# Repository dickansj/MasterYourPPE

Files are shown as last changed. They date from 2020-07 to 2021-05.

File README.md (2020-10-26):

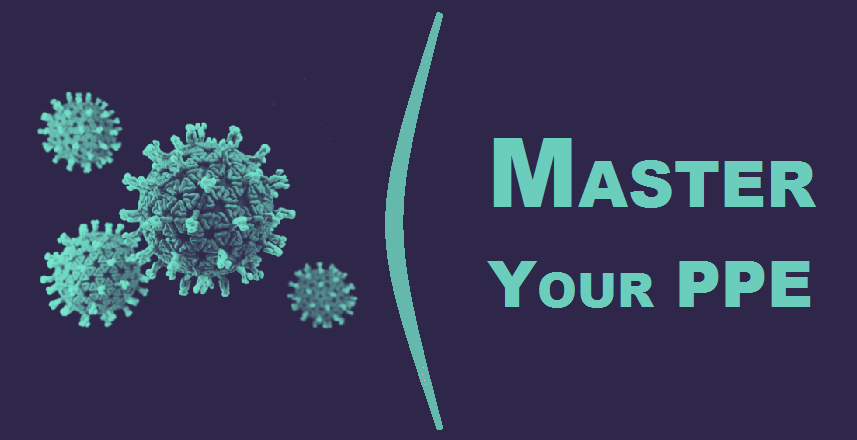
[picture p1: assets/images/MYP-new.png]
Master Your PPE favicon


# Master Your PPE
 

> This repository contains resources for [MasterYourPPE](https://MasterYourPPE.com/), a design project aimed at developing and sharing simple, scalable solutions for better personal protective equipment (PPE). It is built using the [Academic theme](https://sourcethemes.com/academic/) for [Hugo](https://gohugo.io/) and deployed on [Netlify](https://www.netlify.com/).

## Our Vision
*To develop and distribute **easily scalable PPE designs** and simple safe-usage guidelines for the public in order to **protect and educate** the community.*

- We are driven by a focus on maintaining empathy, simplicity, sustainability, and accessibility in our solutions.
- Our goal is to take our PPE designs through the development and iteration process before broadly distributing the ideas.
- Our solutions should be accessible to everyone in our communities, including marginalized and under-resourced groups, and essential workers.
- We plan to collaborate with medical professionals to design the most effective homemade PPE we can, and to spread high-quality information to our community.
- We hope that our work can serve as a framework for others to use and build upon during global health crises now and in the future.

## Getting Started
- Visit https://MasterYourPPE.com/ or our [wiki](https://github.com/dickansj/MasterYourPPE/wiki) to see our array of PPE solutions and resources for healthcare workers and the general public.

- [Contact us](https://masteryourppe.com/#contact) if you are interested in getting involved or finding out more. Have you adapted your PPE to perform better or add comfort? Let us know! We are especially interested to continue hearing from healthcare professionals to engage your experience and better understand your PPE needs.

## License and Disclaimer
The content of this project, including all documentation and hardware designs, is released under the [MIT license](https://github.com/dickansj/MasterYourPPE/blob/master/LICENSE.md) (:copyright: 2020-present Master Your PPE contributors). The Hugo Academic theme (:copyright: 2016-present George Cushen) used to format and display some of this content is also released under the [MIT license](https://github.com/dickansj/MasterYourPPE/blob/master/LICENSE.md).

Our project content has not been reviewed to the standards of the scientific community, and so it should not be construed as medical advice. We believe our testing supports the hypothesis that these designs can make your PPE more effective at protection, but we offer no conclusions regarding health effects or safety. All content is licensed without warranty.

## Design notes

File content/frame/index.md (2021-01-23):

---
title: "Master Your PPE on YouTube"  # Add a page title.
summary: "Easily make your own mask frame to improve the seal and efficacy of your face mask."  # Add a page description.
type: "widget_page"  # Page type is a Widget Page
---

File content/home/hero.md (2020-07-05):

+++
# Hero widget.
widget = "hero"  # See https://sourcethemes.com/academic/docs/page-builder/
headless = true  # This file represents a page section.
active = true  # Activate this widget? true/false
weight = 10  # Order that this section will appear.

title = "Master Your PPE"

# Hero image (optional). Enter filename of an image in the `static/img/` folder.
hero_media = "hero-academic.png"

[design.background]
  # Apply a background color, gradient, or image.
  #   Uncomment (by removing `#`) an option to apply it.
  #   Choose a light or dark text color by setting `text_color_light`.
  #   Any HTML color name or Hex value is valid.

  # Background color.
  # color = "navy"
  
  # Background gradient.
  gradient_start = "#4bb4e3"
  gradient_end = "#2b94c3"
  
  # Background image.
  # image = ""  # Name of image in `static/img/`.
  # image_darken = 0.6  # Darken the image? Range 0-1 where 0 is transparent and 1 is opaque.
  # image_size = "cover"  #  Options are `cover` (default), `contain`, or `actual` size.
  # image_position = "center"  # Options include `left`, `center` (default), or `right`.
  # image_parallax = true  # Use a fun parallax-like fixed background effect? true/false
  
  # Text color (true=light or false=dark).
  text_color_light = true

# Call to action links (optional).
#   Display link(s) by specifying a URL and label below. Icon is optional for `[cta]`.
#   Remove a link/note by deleting a cta/note block.
[cta]
  url = "https://github.com/dickansj/MasterYourPPE/wiki/Improve-Your-Mask-With-a-Frame"
  label = "Step-by-step Guide"
  icon_pack = "fas"
  icon = "list-ol"

[cta_alt]
  url = "https://github.com/dickansj/MasterYourPPE/wiki/Improve-Your-Mask-With-a-Frame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"
  label = "Share results with #MasterYourPPE"

# Note. An optional note to show underneath the links.
## [cta_note]
##   label = '<a class="js-github-release" href="https://sourcethemes.com/academic/updates" data-repo="gcushen/hugo-academic">Latest release<!-- V --></a>'
+++
**to keep yourself and those around you healthy.**

Learn how in this **1-minute video**

<iframe width="100%" height="315" src="https://www.youtube.com/embed/KZgRVWYM7rY" frameborder="0" allow="accelerometer; autoplay; encrypted-media; gyroscope; picture-in-picture" allowfullscreen></iframe>

<!--
<span style="text-shadow: none;"><a class="github-button" href="https://github.com/dickansj/ppe-solutions" data-icon="octicon-star" data-size="large" data-show-count="false" aria-label="Star this on GitHub">Star</a><script async defer src="https://buttons.github.io/buttons.js"></script></span>
-->

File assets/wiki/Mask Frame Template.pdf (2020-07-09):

### Mask Frame Template

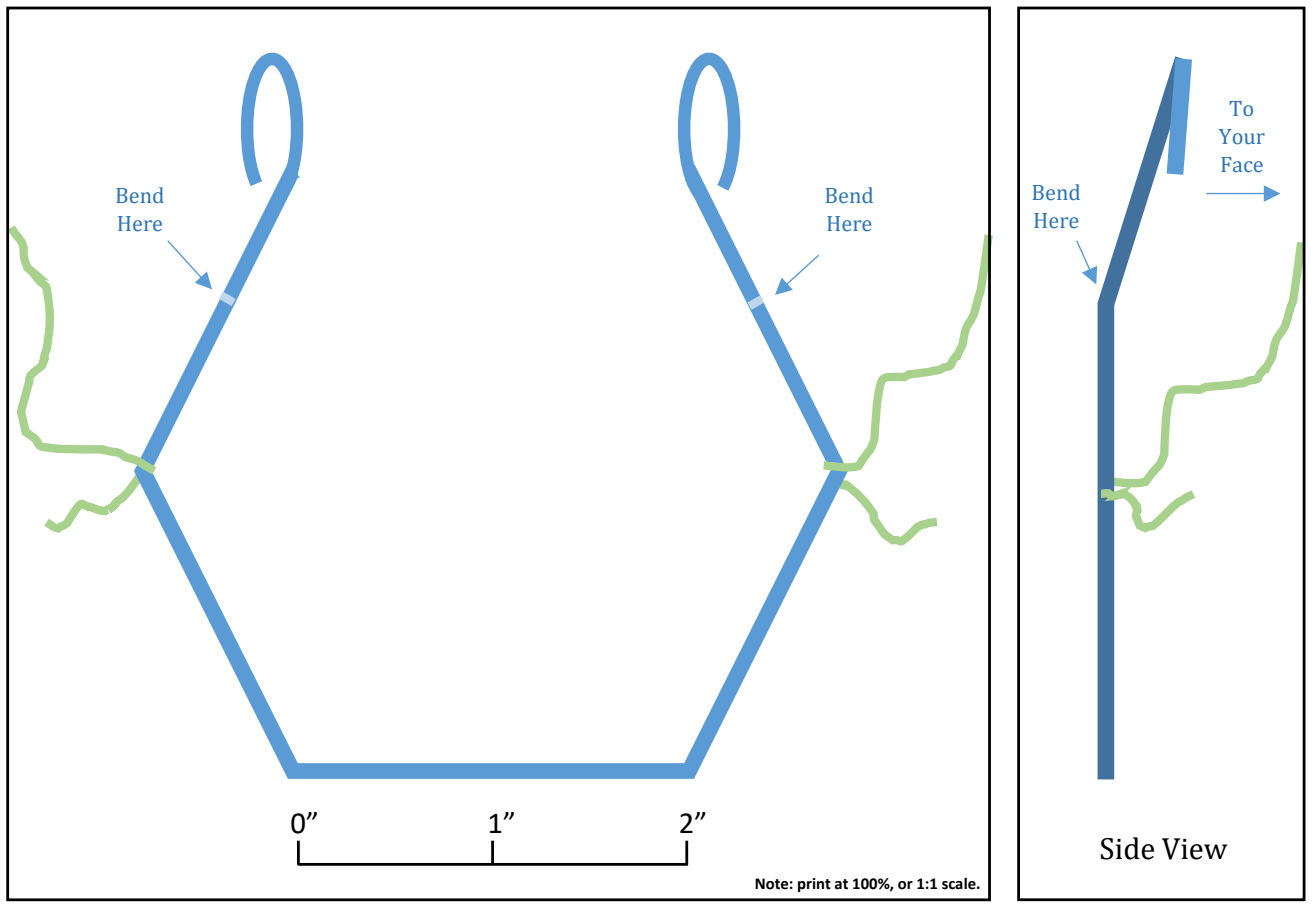
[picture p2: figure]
Side View; Bend Here; To Your Face; Note: print at 100%, or 1:1 scale.

Mask Frame Construction

1. Cut a 12 inch length of 12-gauge solid-core copper wire. Use wire cutters, or use scissors to score the wire then bend it back and forth until it breaks.
2. Loop the wire back about a half inch at both ends for safety. Use long-nose pliers or bend using the spaces in a fork.
3. On a flat surface, like a table, bend the wire into a hexagon shape leaving the top of the shape open. Try to make each side of the hexagon about 2 inches long. You can trace the template above to guide your bending.
4. Bend the wire slightly about an inch from the looped ends to one side of the hexagon shape. This will help push the mask material down against your face and on either side of your nose to stop the side leaks.
5. Cut a 20 inch length of elastic band. Or, take a string or shoelace and measure around your head and cut a length about 3 inches longer than the circumference around your head.
6. Turn the elastic or string once around the wire frame then make a tight knot so that it doesn’t side down the wire too easily. Finally, slide the knots along the wire to the middle bends of the hexagon shape like in the template picture.
7. Looking at yourself in the mirror, put a mask on then place the frame over it. Be careful, the elastic band can snap the frame into your face! Next, bend the wire to adjust the fit of your frame so that it presses comfortably all around your face, especially on either side of your nose. You may need to adjust the length of the elastic or string if the frame feels too tight or too loose. A good test is wearing glasses, if they fog up, the frame isn’t doing its job.

Tips: Pull out a bit of mask material in front of your mouth for breathing comfort. The mask and frame should be comfortable to wear for about 2 hours. Find a safe place to remove your mask and give your face a few minutes to breathe and recover.

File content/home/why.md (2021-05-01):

+++

## This is a template for a blank page section.
## Copy into a new md file. Remember to change active to "true" and use weight to set order on page.
## You can use the other options below, just uncomment as needed.
## Place any html after the bottom 3 plus signs. You can use the div container with Bootstrap classes.
## See https://getbootstrap.com/docs/4.5/layout/grid/ and the docs there (or other content/home md files on this site) for examples.

widget = "blank"  # See https://sourcethemes.com/academic/docs/page-builder/
headless = true  # This file represents a page section.
active = true  # Activate this widget? true/false
weight = 10  # Order that this section will appear.

title = ""
subtitle = ""

[design]
  # Choose how many columns the section has. Valid values: 1 or 2.
  columns = "1"

[design.background]
  # Apply a background color, gradient, or image.
  #   Uncomment (by removing `#`) an option to apply it.
  #   Choose a light or dark text color by setting `text_color_light`.
  #   Any HTML color name or Hex value is valid.

  # Background color.
  # color = "navy"
  
  # Background gradient.
  #gradient_start = "#80CED7"
  #gradient_end = "#007EA7"
  
  # Background image.
  # image = "image.jpg"  # Name of image in `static/img/`.
  # image_darken = 0.6  # Darken the image? Range 0-1 where 0 is transparent and 1 is opaque.
  # image_size = "cover"  #  Options are `cover` (default), `contain`, or `actual` size.
  # image_position = "center"  # Options include `left`, `center` (default), or `right`.
  # image_parallax = true  # Use a fun parallax-like fixed background effect? true/false
  
  # Text color (true=light or false=dark).
  text_color_light = false

[design.spacing]
  # Customize the section spacing. Order is top, right, bottom, left.
  padding = ["20px", "0", "20px", "0"]

[advanced]
 # Custom CSS. 
 css_style = ""
 
 # CSS class.
 css_class = ""
+++

<div class="container-fluid">
  <div class="row featurette">
    <div class="col-xs-12 col-sm-12 col-md-12 col-lg-12 col-xl-12 section-heading">
      <h1><b>Master your PPE!</b></h1>
    </div>
  </div> 
  <div class="row align-items-center">
        
    <div class="col-xs-6 col-sm-6 col-md-6 col-lg-6 col-xl-6" style="text-align: center">
      <span class="lead"; style="color: #83cabb">&#35;myppe</span>&nbsp;&nbsp;<a href="https://www.instagram.com/masteryourppe/" target="_blank"><i class="fab fa-instagram fa-lg"></i></a>&nbsp;&nbsp;<a href="https://www.youtube.com/channel/UCWnhMrXAAiUKiis0FMS9hzg" target="_blank"><i class="fab fa-youtube"></i></a>&nbsp;&nbsp;<a href="https://www.linkedin.com/company/master-your-ppe" target="_blank"><i class="fab fa-linkedin-in fa-lg"></i></a>
    </div>
    
  </div>
  <div class="row align-items-center my-4">
    <div class="col-xs-12 col-sm-12 col-md-6 col-lg-4 col-xl-4">
      <h3>I have my mask . . . now what?</h3>
      <p class="text-left">You know <b><a href="https://www.cdc.gov/coronavirus/2019-ncov/index.html" target="_blank">COVID-19</a></b> is <b><a href="https://covid19.who.int/" target="_blank">still here</a></b>, and you're doing your part to protect yourself and others. Since infections frequently occur when people <b><a href="https://www.nytimes.com/2020/08/11/health/coronavirus-aerosols-indoors.html" target="_blank">breathe in</a></b> contaminated droplets, we need to social distance and correctly wear personal protective equipment (PPE) in order to overcome the virus.</p>
    </div>
    <div class="col-xs-12 col-sm-12 col-md-6 col-lg-3 col-xl-3">
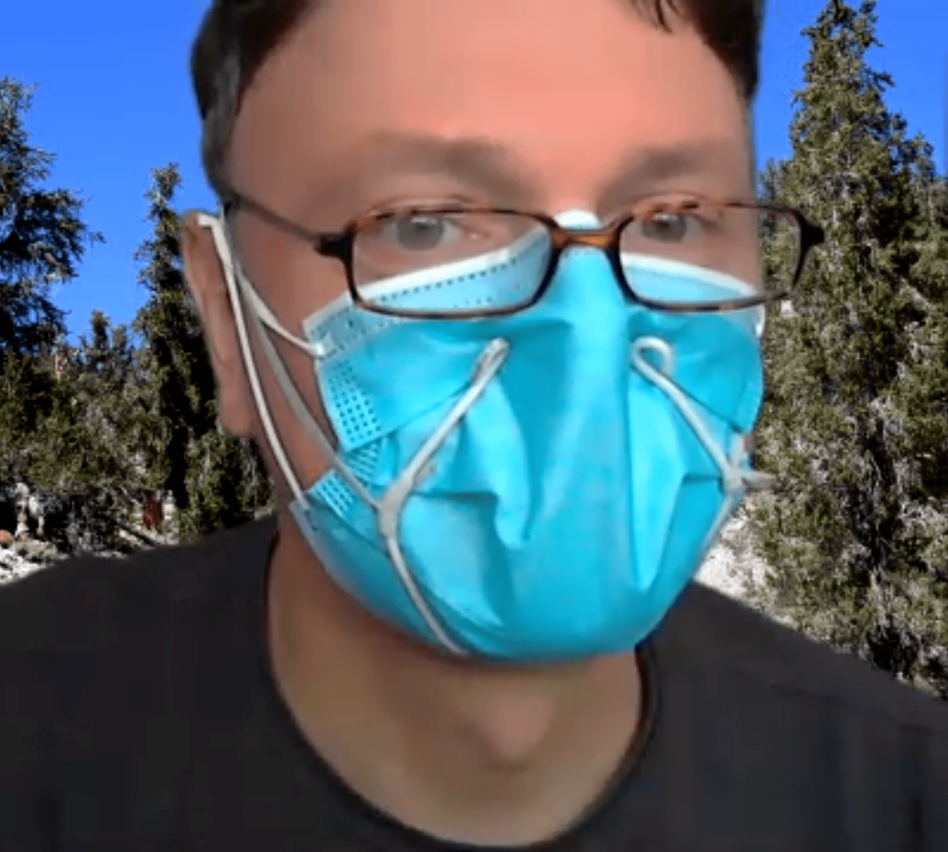
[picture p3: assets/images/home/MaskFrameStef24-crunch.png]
A face mask and mask frame are simple, effective PPE
      
      <p class="text-center"><small><em>Want to make your own mask frame?</em></small><br><b><a href="https://www.youtube.com/watch?v=kpPfyq7r8vA" target="_blank">It's easy, and here's how.</a></b></p>
    </div>
    <div class="col-xs-12 col-sm-12 col-md-12 col-lg-5 col-xl-5">
      <h3>OK, but I'm ready to do more.</h3>
      <p class="text-left">Here you will find <b><a href="https://www.masteryourppe.com/tips/" target="_blank">tips</a></b> and resources to improve the filtration and practicality of your PPE.</p>
      <p class="text-left">Good face coverings can fail because of a weak seal that lets unfiltered air escape or enter through gaps along the sides. By using a simple <b><a href="https://www.youtube.com/watch?v=kpPfyq7r8vA" target="_blank">mask frame</a></b> like the one pictured here, you can effectively reduce the chance of inhaling infected droplets or spreading them to others.</p>
    </div>
  </div> 

</div>

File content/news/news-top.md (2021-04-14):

+++

widget = "blank"  # See https://sourcethemes.com/academic/docs/page-builder/
headless = true  # This file represents a page section.
active = true  # Activate this widget? true/false
weight = 10  # Order that this section will appear.

title = ""
subtitle = ""

[design]
  # Choose how many columns the section has. Valid values: 1 or 2.
  columns = "1"

[design.background]
  # Apply a background color, gradient, or image.
  #   Uncomment (by removing `#`) an option to apply it.
  #   Choose a light or dark text color by setting `text_color_light`.
  #   Any HTML color name or Hex value is valid.

  # Background color.
  # color = "navy"
  
  # Background gradient.
  #gradient_start = "#80CED7"
  #gradient_end = "#007EA7"
  
  # Background image.
  # image = "image.jpg"  # Name of image in `static/img/`.
  # image_darken = 0.6  # Darken the image? Range 0-1 where 0 is transparent and 1 is opaque.
  # image_size = "cover"  #  Options are `cover` (default), `contain`, or `actual` size.
  # image_position = "center"  # Options include `left`, `center` (default), or `right`.
  # image_parallax = true  # Use a fun parallax-like fixed background effect? true/false
  
  # Text color (true=light or false=dark).
  text_color_light = false

[design.spacing]
  # Customize the section spacing. Order is top, right, bottom, left.
  padding = ["20px", "0", "20px", "0"]

[advanced]
 # Custom CSS. 
 css_style = ""
 
 # CSS class.
 css_class = ""
+++

<script src="https://raw.githubusercontent.com/dickansj/MasterYourPPE/master/assets/js/newsCollapse.js"></script>

<div class="container" style="min-width: 0; min-height: 0">

  <div class="row align-items-center px-0" style="justify-content: space-evenly; min-width: 0; min-height: 0; overflow:hidden; flex-wrap:nowrap">
    <div class="col-xs-3 col-sm-3 col-md-3 col-lg-3 col-xl-3 mb-4 px-0" style="min-width: 0; min-height: 0">
      <button class="btn" type="button" style="min-width: 0" data-toggle="collapse" data-target="#science" role="button" aria-expanded="false" aria-controls="science" onclick="location.href = '#articles';">
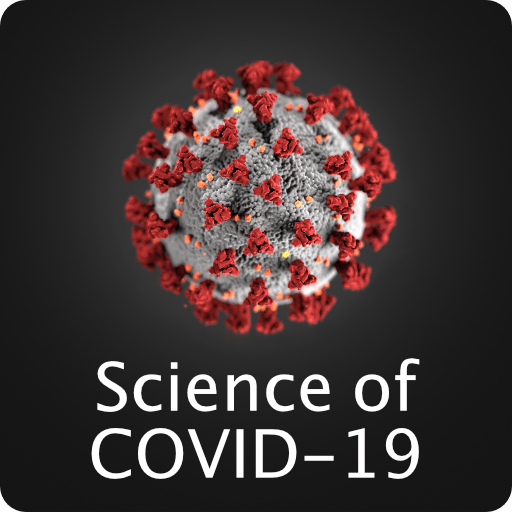
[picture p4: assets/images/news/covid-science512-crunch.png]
Coronavirus Science
        
      </button>
    </div>
    <div class="col-xs-3 col-sm-3 col-md-3 col-lg-3 col-xl-3 mb-4 px-0" style="min-width: 0; min-height: 0">
      <button class="btn" type="button" style="min-width: 0" data-toggle="collapse" data-target="#healthcare" role="button" aria-expanded="false" aria-controls="healthcare" onclick="location.href = '#articles';">
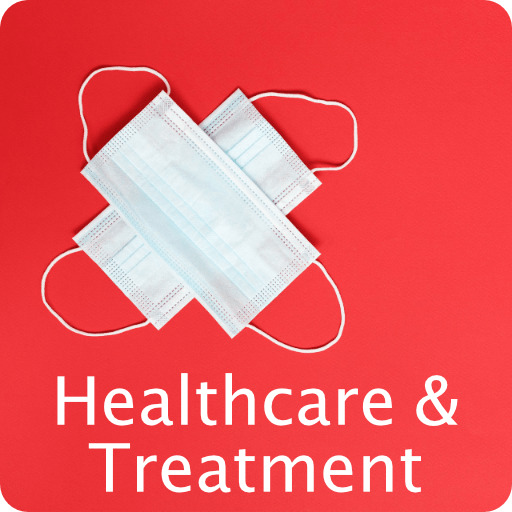
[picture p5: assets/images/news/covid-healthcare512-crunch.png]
Healthcare and Treatment
        
      </button>
    </div>
    <div class="col-xs-3 col-sm-3 col-md-3 col-lg-3 col-xl-3 mb-4 px-0" style="min-width: 0; min-height: 0">
      <button class="btn" type="button" style="min-width: 0" onclick="window.open('https://covid19.who.int/','_blank');">
        <img class="img-fluid" style="box-shadow: 0.4em 0.5em 0.75em -0.3em; border-radius: 1.7em" src="https://github.com/dickansj/MasterYourPPE/blob/master/assets/images/news/who-dashboard512-crunch.png?raw=true alt="WHO Coronavirus Dashboard">
      </button>
    </div>
  </div>

  <p></p>

  <div class="collapse show" id="science">
    <div class="row align-items-center justify-content-around">
      <div class="col-xs-12 col-sm-12 col-md-9 col-lg-9 col-xl-8 my-4">
        <div class="card">
          <div class="card-header lead" style="font-weight: bold; text-align: center">Science of COVID-19</div>
          <a href="https://www.bmj.com/content/372/bmj.n579" target="_blank">
            
          </a>
          <div class="card-body">
            <a href="https://www.bmj.com/content/372/bmj.n579" target="_blank">
              <h5 class="card-title">Risk of Mortality in Patients Infected With SARS-CoV-2 Variant of Concern 202012/1: Matched Cohort Study</h5>
            </a>
            <p class="card-text text-left" style="font-style: italic">A matched cohort study of patients infected with SARS-CoV-2 found a significantly increased mortality risk associated with the viral variant VOC-202012/01.</p>
          </div>
          <div class="card-footer">
            <small class="text-muted">BMJ | Robert Challen, Ellen Brooks-Pollock, Jonathan M. Read, et al.</small>
          </div>
        </div>
      </div>
    </div>
    <div class="row align-items-center justify-content-around">
      <div class="col-xs-12 col-sm-12 col-md-9 col-lg-9 col-xl-8">
        <div class="card">
          <div class="card-header" style="font-weight: bold; text-align: center">More on the Science of COVID-19</div>
          <div class="card-body">
            <p></p>
            <ul><a href="https://jamanetwork.com/journals/jamainternalmedicine/fullarticle/2773576" target="_blank">Estimated SARS-CoV-2 Seroprevalence in the US as of September 2020</a><small class="text-muted"> | JAMA Intern. Med.</small></ul>
            <ul><a href="https://english.elpais.com/society/2020-10-28/a-room-a-bar-and-a-class-how-the-coronavirus-is-spread-through-the-air.html" target="_blank">A Room, a Bar and a Classroom: How the Coronavirus Is Spread Through the Air</a><small class="text-muted"> | El Pais</small></ul>
            <ul><a href="https://amp.cnn.com/cnn/2020/10/30/health/household-spread-covid-19-wellness/index.html" target="_blank">Household Spread of COVID-19 Is Common and Quick, a New CDC Study Finds</a><small class="text-muted"> | CNN</small></ul>
            <ul><a href="https://ashpublications.org/bloodadvances/article/4/20/4990/463793" target="_blank">Reduced Prevalence of SARS-CoV-2 Infection in ABO Blood Group O</a><small class="text-muted"> | Blood Advances</small></ul>
            <ul><a href="https://elemental.medium.com/a-supercomputer-analyzed-covid-19-and-an-interesting-new-theory-has-emerged-31cb8eba9d63" target="_blank">A Supercomputer Analyzed Covid-19 — and an Interesting New Theory Has Emerged</a><small class="text-muted"> | Medium</small></ul>
            <ul><a href="https://depts.washington.edu/pandemicalliance/covid-19-literature-report/latest-reports/" target="_blank">COVID-19 Literature Report (Pre-Prints)</a><small class="text-muted"> | Univ. Washington</small></ul>
            <ul><a href="https://www.nature.com/articles/d41586-020-00502-w" target="_blank">Ongoing Summary of Key COVID-19 Papers</a><small class="text-muted"> | Nature</small></ul>
            <ul><a href="https://www.sciencemag.org/news/2020/09/hidden-immune-weakness-found-14-gravely-ill-covid-19-patients" target="_blank">Hidden Immune Weakness Found in 14% of Gravely Ill COVID-19 Patients</a><small class="text-muted"> | Science</small></ul>
          </div>
        </div>
      </div>     
    </div>
  </div>

  <div class="collapse" id="healthcare">
    <div class="row align-items-center justify-content-around">
      <div class="col-xs-12 col-sm-12 col-md-9 col-lg-9 col-xl-8 my-4">
        <div class="card">
          <div class="card-header lead" style="font-weight: bold; text-align: center">Healthcare & Treatment</div>
          <a href="https://www.nature.com/articles/d41586-021-00722-8" target="_blank">
            
          </a>
          <div class="card-body">
            <a href="https://www.nature.com/articles/d41586-021-00722-8" target="_blank">
              <h5 class="card-title">Rare COVID Reactions Might Hold Key to Variant-Proof Vaccines</h5>
            </a>
            <p class="card-text text-left" style="font-style: italic">Some people mount an immune response able to fend off a menagerie of coronavirus variants.</p>
          </div>
          <div class="card-footer">
            <small class="text-muted">Nature | Ewen Callaway</small>
          </div>
        </div>
      </div>
    </div>
    <div class="row align-items-center justify-content-around">
      <div class="col-xs-12 col-sm-12 col-md-9 col-lg-9 col-xl-8">
        <div class="card">
          <div class="card-header" style="font-weight: bold; text-align: center">More on Healthcare & Treatment</div>
          <div class="card-body">
            <p></p>
            <ul><a href="https://www.newscientist.com/article/2261092-do-oxford-astrazeneca-covid-19-vaccine-results-stand-up-to-scrutiny/" target="_blank">Do Oxford/AstraZeneca COVID-19 Vaccine Results Stand Up to Scrutiny?</a><small class="text-muted"> | New Scientist</small></ul>
            <ul><a href="https://www.ashp.org/-/media/8CA43C674C6D4335B6A19852843C4052.ashx" target="_blank">Assessment of Evidence for COVID-19-Related Treatment: An Updated Summary of Treatments</a><small class="text-muted"> | Amer. Soc. of Health-System Pharmacists</small></ul>            
            <ul><a href="https://www.sciencemag.org/news/2020/09/provocative-results-boost-hopes-antibody-treatment-covid-19" target="_blank">Regeneron’s ‘Provocative Results’ Boost Hopes of Antibody Treatment for COVID-19</a><small class="text-muted"> | Science</small></ul>
            <ul><a href="https://coronavirus.jhu.edu/covid-19-basics/understanding-covid-19" target="_blank">Understanding the COVID-19 Pandemic (Public Online Course)</a><small class="text-muted"> | Johns Hopkins University</small></ul>
            <ul><a href="https://coronavirus.jhu.edu/news" target="_blank">Curated Updates From the Coronavirus Resource Center</a><small class="text-muted"> | Johns Hopkins University</small></ul>
          </div>
        </div>
      </div>     
    </div>
  </div>
  
</div>

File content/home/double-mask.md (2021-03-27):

+++

## This is a template for a blank page section.
## Copy into a new md file. Remember to change active to "true" and use weight to set order on page.
## You can use the other options below, just uncomment as needed.
## Place any html after the bottom 3 plus signs. You can use the div container with Bootstrap classes.
## See https://getbootstrap.com/docs/4.5/layout/grid/ and the docs there (or other content/home md files on this site) for examples.

widget = "blank"  # See https://sourcethemes.com/academic/docs/page-builder/
headless = true  # This file represents a page section.
active = true  # Activate this widget? true/false
weight = 20  # Order that this section will appear.

title = ""
subtitle = ""

[design]
  # Choose how many columns the section has. Valid values: 1 or 2.
  columns = "1"

[design.background]
  # Apply a background color, gradient, or image.
  #   Uncomment (by removing `#`) an option to apply it.
  #   Choose a light or dark text color by setting `text_color_light`.
  #   Any HTML color name or Hex value is valid.

  # Background color.
  # color = "navy"
  
  # Background gradient.
  #gradient_start = "#80CED7"
  #gradient_end = "#007EA7"
  
  # Background image.
  # image = "image.jpg"  # Name of image in `static/img/`.
  # image_darken = 0.6  # Darken the image? Range 0-1 where 0 is transparent and 1 is opaque.
  # image_size = "cover"  #  Options are `cover` (default), `contain`, or `actual` size.
  # image_position = "center"  # Options include `left`, `center` (default), or `right`.
  # image_parallax = true  # Use a fun parallax-like fixed background effect? true/false
  
  # Text color (true=light or false=dark).
  text_color_light = false

[design.spacing]
  # Customize the section spacing. Order is top, right, bottom, left.
  padding = ["20px", "0", "20px", "0"]

[advanced]
 # Custom CSS. 
 css_style = ""
 
 # CSS class.
 css_class = ""
+++

<div class="container-fluid">
  <div class="row align-items-center justify-content-between my-4">
    <div class="col-xs-12 col-sm-12 col-md-6 col-lg-4 col-xl-4">
      <h3>What about "double-masking"?</h3>
      <p class="text-left">CDC recently recommended several <b><a href="https://www.cdc.gov/mmwr/volumes/70/wr/mm7007e1.htm?s_cid=mm7007e1_w" target="_blank">mask modifications</a></b> to increase fit, including the use of a mask fitter (frame) or wearing a second mask over a procedure mask.</p>
    </div>
    <div class="col-xs-12 col-sm-12 col-md-6 col-lg-6 col-xl-6">
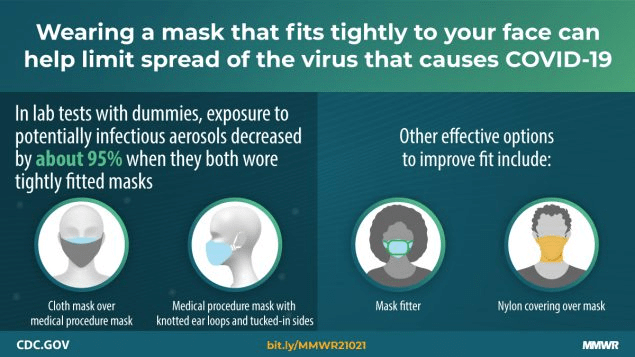
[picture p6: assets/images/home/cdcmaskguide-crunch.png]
CDC mask fit techniques
    	
    </div>
  </div>
  <div class="row align-items-center justify-content-between my-4">
    <div class="col-xs-12 col-sm-12 col-md-6 col-lg-4 col-xl-4">
      <p class="text-left">Watch how we tested our simple mask frame against double-masking to see which approach better prevents unfiltered air leaks. Our results suggest the frame more effectively filters air--all without making it tough to breathe.</p>
    </div>
    <div class="col-xs-12 col-sm-12 col-md-6 col-lg-6 col-xl-6 video-container">
    	<iframe src="https://www.youtube.com/embed/lS0DN3vC22w" frameborder="0" allow="accelerometer; autoplay; encrypted-media; gyroscope; picture-in-picture" allowfullscreen></iframe>
    </div>
  </div> 

</div>

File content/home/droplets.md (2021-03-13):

+++

## This is a template for a blank page section.
## Copy into a new md file. Remember to change active to "true" and use weight to set order on page.
## You can use the other options below, just uncomment as needed.
## Place any html after the bottom 3 plus signs. You can use the div container with Bootstrap classes.
## See https://getbootstrap.com/docs/4.5/layout/grid/ and the docs there (or other content/home md files on this site) for examples.

widget = "blank"  # See https://sourcethemes.com/academic/docs/page-builder/
headless = true  # This file represents a page section.
active = true  # Activate this widget? true/false
weight = 40  # Order that this section will appear.

title = ""
subtitle = ""

[design]
  # Choose how many columns the section has. Valid values: 1 or 2.
  columns = "1"

[design.background]
  # Apply a background color, gradient, or image.
  #   Uncomment (by removing `#`) an option to apply it.
  #   Choose a light or dark text color by setting `text_color_light`.
  #   Any HTML color name or Hex value is valid.

  # Background color.
  # color = "navy"
  
  # Background gradient.
  #gradient_start = "#80CED7"
  #gradient_end = "#007EA7"
  
  # Background image.
  # image = "image.jpg"  # Name of image in `static/img/`.
  # image_darken = 0.6  # Darken the image? Range 0-1 where 0 is transparent and 1 is opaque.
  # image_size = "cover"  #  Options are `cover` (default), `contain`, or `actual` size.
  # image_position = "center"  # Options include `left`, `center` (default), or `right`.
  # image_parallax = true  # Use a fun parallax-like fixed background effect? true/false
  
  # Text color (true=light or false=dark).
  text_color_light = false

[design.spacing]
  # Customize the section spacing. Order is top, right, bottom, left.
  padding = ["20px", "0", "20px", "0"]

[advanced]
 # Custom CSS. 
 css_style = ""
 
 # CSS class.
 css_class = ""
+++

<div class="container-fluid">
  
  <div class="row align-items-xl-center">
    <div class="col-xs-12 col-sm-12 col-md-6 col-lg-6 col-xl-8">
      <h3>What is really going on?</h3>
      <p class="text-left">The <b><a href="https://www.nytimes.com/2020/08/11/health/coronavirus-aerosols-indoors.html" target="_blank">latest research</a></b> confirms that most people become infected with Covid-19 by inhaling contaminated droplets that are ejected when talking, singing, eating, sneezing, coughing, etc.</p>
      <p class="text-left">Infectious virus particles have been observed in both large and small droplets. Larger droplets vary in size down to 0.5mm. These fall to the ground quickly, usually within 6 feet of where they are generated.</p>
    </div>
    <div class="col-xs-12 col-sm-12 col-md-6 col-lg-6 col-xl-4 my-4 order-xs-last order-sm-last order-md-first order-lg-first order-xl-first">
      The spread of droplets
    </div>
  </div>

  <div class="row">
    <div class="col-xs-12 col-sm-12 col-md-12 col-lg-12 col-xl-12">
      <p class="text-left">Smaller droplets range in size from about 0.5mm down to 0.001mm and can <b><a href="https://economictimes.indiatimes.com/news/science/coronavirus-can-travel-up-to-8-metres-from-exhalation-linger-in-air-for-hours-mit-scientist-says/articleshow/749283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" target="_blank">remain suspended in air for hours.</a></b> These can also travel long distances on air currents.  In enclosed environments with still air, small droplets can accumulate in the area where they are being generated until the area becomes <b><a href="https://english.elpais.com/society/2020-10-28/a-room-a-bar-and-a-class-how-the-coronavirus-is-spread-through-the-air.html" target="_blank">highly infectious</a></b>.</p>
      <p class="text-left">For these reasons, it is important to wear an <b><a href="https://www.masteryourppe.com/testing/" target="_blank">effective face covering</a></b> and avoid crowds. And, to help lower the risk of Covid-19 transmission further, see these mask-wearing <b><a href="https://www.masteryourppe.com/tips">tips and tricks</a></b>.</p>
    </div>
  </div>

</div>

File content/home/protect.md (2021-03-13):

+++

## This is a template for a blank page section.
## Copy into a new md file. Remember to change active to "true" and use weight to set order on page.
## You can use the other options below, just uncomment as needed.
## Place any html after the bottom 3 plus signs. You can use the div container with Bootstrap classes.
## See https://getbootstrap.com/docs/4.5/layout/grid/ and the docs there (or other content/home md files on this site) for examples.

widget = "blank"  # See https://sourcethemes.com/academic/docs/page-builder/
headless = true  # This file represents a page section.
active = false  # Activate this widget? true/false
weight = 20  # Order that this section will appear.

title = ""
subtitle = ""

[design]
  # Choose how many columns the section has. Valid values: 1 or 2.
  columns = "1"

[design.background]
  # Apply a background color, gradient, or image.
  #   Uncomment (by removing `#`) an option to apply it.
  #   Choose a light or dark text color by setting `text_color_light`.
  #   Any HTML color name or Hex value is valid.

  # Background color.
  # color = "navy"
  
  # Background gradient.
  #gradient_start = "#80CED7"
  #gradient_end = "#007EA7"
  
  # Background image.
  # image = "image.jpg"  # Name of image in `static/img/`.
  # image_darken = 0.6  # Darken the image? Range 0-1 where 0 is transparent and 1 is opaque.
  # image_size = "cover"  #  Options are `cover` (default), `contain`, or `actual` size.
  # image_position = "center"  # Options include `left`, `center` (default), or `right`.
  # image_parallax = true  # Use a fun parallax-like fixed background effect? true/false
  
  # Text color (true=light or false=dark).
  text_color_light = false

[design.spacing]
  # Customize the section spacing. Order is top, right, bottom, left.
  padding = ["20px", "0", "20px", "0"]

[advanced]
 # Custom CSS. 
 css_style = ""
 
 # CSS class.
 css_class = ""
+++

<div class="container-fluid">
  <div class="row align-items-center mt-4">
    <div class="col-xs-12 col-sm-12 col-md-4 col-lg-4 col-xl-4">
      <h3>Will a mask protect me?</h3>
      <p class="text-left">A good face covering that is worn correctly will substantially reduce the chance of breathing infected airborne droplets or of spreading infectious particles to others.</p>
    </div>
    <div class="col-xs-12 col-sm-12 col-md-8 col-lg-8 col-xl-8">
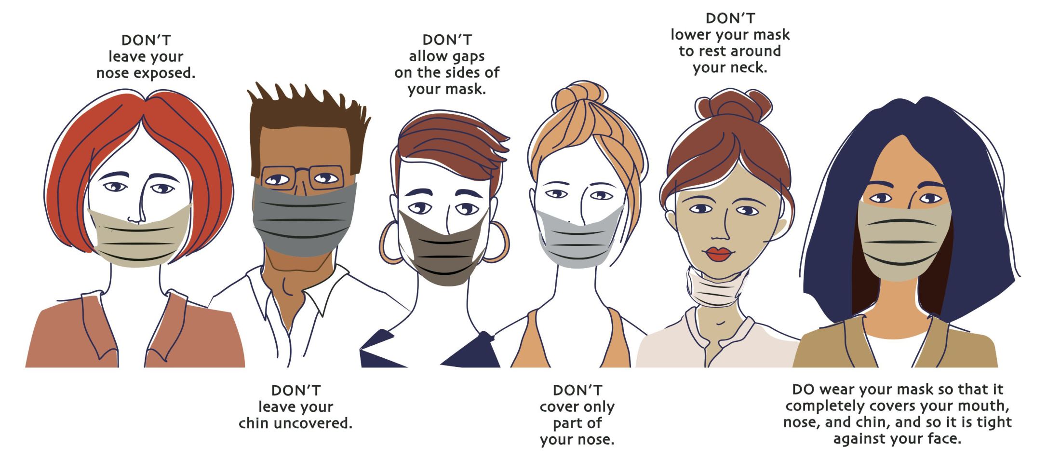
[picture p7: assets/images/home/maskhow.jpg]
How to properly wear a mask
      
      <p class="text-muted small">Graphic by Hollister Breslin</p>
    </div>
  </div> 
  <div class="row">
    <div class="col-xs-12 col-sm-12 col-md-12 col-lg-12 col-xl-12">
      <p class="text-left">Noting the concentration and persistence of small droplets within enclosed areas, it is very important that everyone wear a good face covering. This is to prevent droplets from accumulating in breathing spaces. And of course, it’s prudent to continue to wash hands often, and to avoid crowds.</p>
    </div>
  </div> 
  
</div>

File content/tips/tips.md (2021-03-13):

+++

## This is a template for a blank page section.
## Copy into a new md file. Remember to change active to "true" and use weight to set order on page.
## You can use the other options below, just uncomment as needed.
## Place any html after the bottom 3 plus signs. You can use the div container with Bootstrap classes.
## See https://getbootstrap.com/docs/4.5/layout/grid/ and the docs there (or other content/home md files on this site) for examples.

widget = "blank"  # See https://sourcethemes.com/academic/docs/page-builder/
headless = true  # This file represents a page section.
active = true  # Activate this widget? true/false
weight = 40  # Order that this section will appear.

aliases = [
  "/action/"
]

title = ""
subtitle = ""

[design]
  # Choose how many columns the section has. Valid values: 1 or 2.
  columns = "1"

[design.background]
  # Apply a background color, gradient, or image.
  #   Uncomment (by removing `#`) an option to apply it.
  #   Choose a light or dark text color by setting `text_color_light`.
  #   Any HTML color name or Hex value is valid.

  # Background color.
  # color = "navy"
  
  # Background gradient.
  #gradient_start = "#80CED7"
  #gradient_end = "#007EA7"
  
  # Background image.
  # image = "image.jpg"  # Name of image in `static/img/`.
  # image_darken = 0.6  # Darken the image? Range 0-1 where 0 is transparent and 1 is opaque.
  # image_size = "cover"  #  Options are `cover` (default), `contain`, or `actual` size.
  # image_position = "center"  # Options include `left`, `center` (default), or `right`.
  # image_parallax = true  # Use a fun parallax-like fixed background effect? true/false
  
  # Text color (true=light or false=dark).
  text_color_light = false

[design.spacing]
  # Customize the section spacing. Order is top, right, bottom, left.
  padding = ["20px", "0", "20px", "0"]

[advanced]
 # Custom CSS. 
 css_style = ""
 
 # CSS class.
 css_class = ""
+++

<div class="container-fluid">
  <div class="row">
    <div class="col-xs-12 col-sm-12 col-md-12 col-lg-12 col-xl-12 text-center">
      <h3>What PPE should I wear?</h3>
    </div>
  </div> 
  <div class="row">
    <div class="col-xs-12 col-sm-12 col-md-12 col-lg-12 col-xl-12">
      <p class="text-left">After <b><a href="https://www.masteryourppe.com/testing" target="_blank">testing the filtering efficiency</a></b> of several face masks and common materials used for face coverings, we find that 3-layer disposable masks are very effective at trapping potentially infections airborne droplets. These common mask types are sold at neighborhood drug stores and most hardware stores.  Specifically, look for 3-layer masks (aka surgical masks). And remember to always carry two masks with you: one to wear and one as a spare, in your car, your bag, or your pocket.</p>
    </div>
  </div> 
  <div class="row">
    <div class="col-xs-12 col-sm-12 col-md-12 col-lg-12 col-xl-12 text-center">
      <h3>How do I properly wear a surgical mask?</h3>
    </div>
  </div> 
  <div class="row">
    <div class="col-xs-12 col-sm-12 col-md-12 col-lg-12 col-xl-12">
      <p class="text-left">Wearing a surgical mask correctly may not be obvious.  There are basically <b>two things</b> you must do (in addition to actually wearing the mask on your face, not on your head or under your chin) when in a public setting.  First, pull open the pleats so that the mask covers your chin completely.  Second, bend the nose clip wire down onto your face to customize the fit and seal of the mask.</p>
    </div>
  </div>
  <div class="row my-4">
    <div class="col-xs-12 col-sm-12 col-md-12 col-lg-12 col-xl-12 text-center">
      <h3>What else can I do?</h3>
    </div>
  </div>
  <div class="row align-items-center">
    <div class="col-xs-12 col-sm-12 col-md-8 col-lg-8 col-xl-8">
      <h4>Check your mask type.</h4>
      <p class="text-left">A quick way to check that you have a 3-layer mask, is to cut one open and count the layers.  The two outer ‘hydrophobic’ layers are used to repel moisture, while the inside layer is the melt-blown filter.</p>
      <p class="text-left">By comparison, 2-layer masks lack the innermost filtering layer.  These masks perform poorly at filtering smaller droplets.  Two-layer masks are typically sold at beauty supply stores.</p>
    </div>
    <div class="col-xs-12 col-sm-12 col-md-4 col-lg-4 col-xl-4 order-xs-last order-sm-last order-md-first order-lg-first order-xl-first my-4">
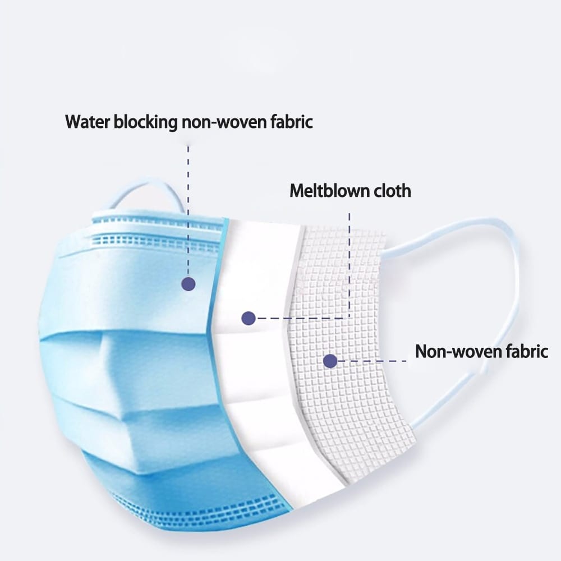
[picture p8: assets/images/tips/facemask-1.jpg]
Check your mask type
      
    </div>
  </div>
  <div class="row align-items-center">
    <div class="col-xs-12 col-sm-12 col-md-8 col-lg-8 col-xl-8">
      <h4>Clips the trick.</h4>
      <p class="text-left">Attach a paper clip to each side of a baseball cap then attach the ear loops of a surgical mask to the clips.  This will save you from having to wear the mask loops around your ears.  Or, if you have access to a 3-D printer, download and print <b><a href="https://github.com/dickansj/MasterYourPPE/blob/master/designs/facemask/maskclip/MaskClipv3.stl" target="_blank">this cap clip STL file</a></b> to do the same thing, in style.</p>
    </div>
    <div class="col-xs-12 col-sm-12 col-md-4 col-lg-4 col-xl-4 order-xs-last order-sm-last order-md-first order-lg-first order-xl-first my-4">
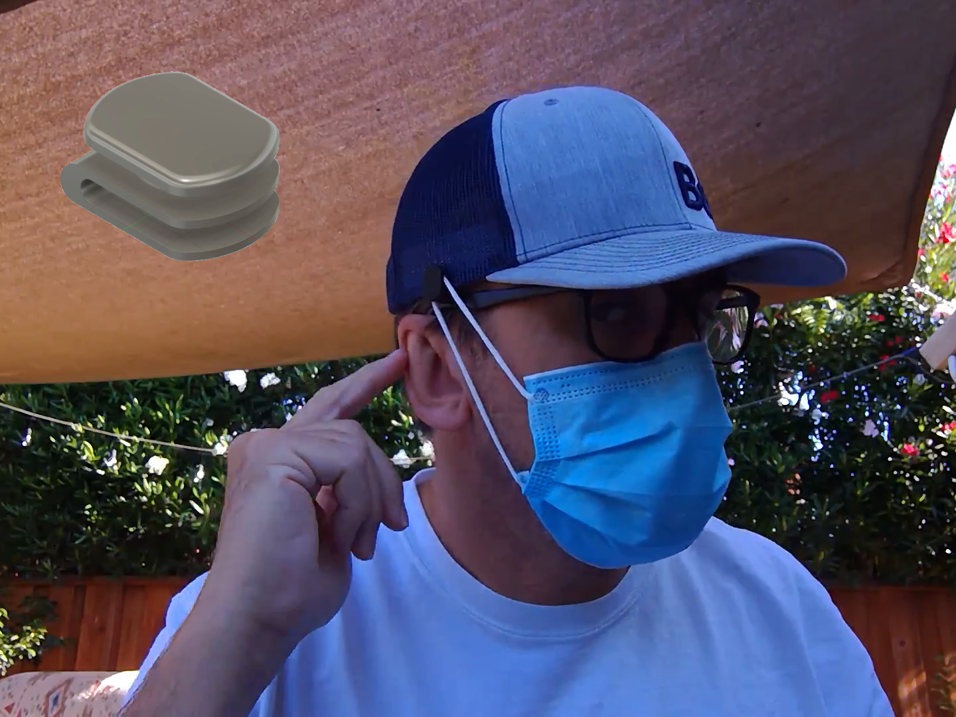
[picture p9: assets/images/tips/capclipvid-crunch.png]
Cap clips will keep your mask loops from straining your ears
      
    </div>
  </div> 
  <div class="row align-items-center">
    <div class="col-xs-12 col-sm-12 col-md-8 col-lg-8 col-xl-8">
      <h4>Some strings attached.</h4>
      <p class="text-left">Tie a string between the ear loops of your mask.  This will keep the loops from rubbing or digging into the skin behind your ears after hours of use.  You can also use the elastic ear loop string itself for this purpose.  Just rip off an ear loop string from an old mask on its way to being trashed.</p>
    </div>
    <div class="col-xs-12 col-sm-12 col-md-4 col-lg-4 col-xl-4 order-xs-last order-sm-last order-md-first order-lg-first order-xl-first my-4">
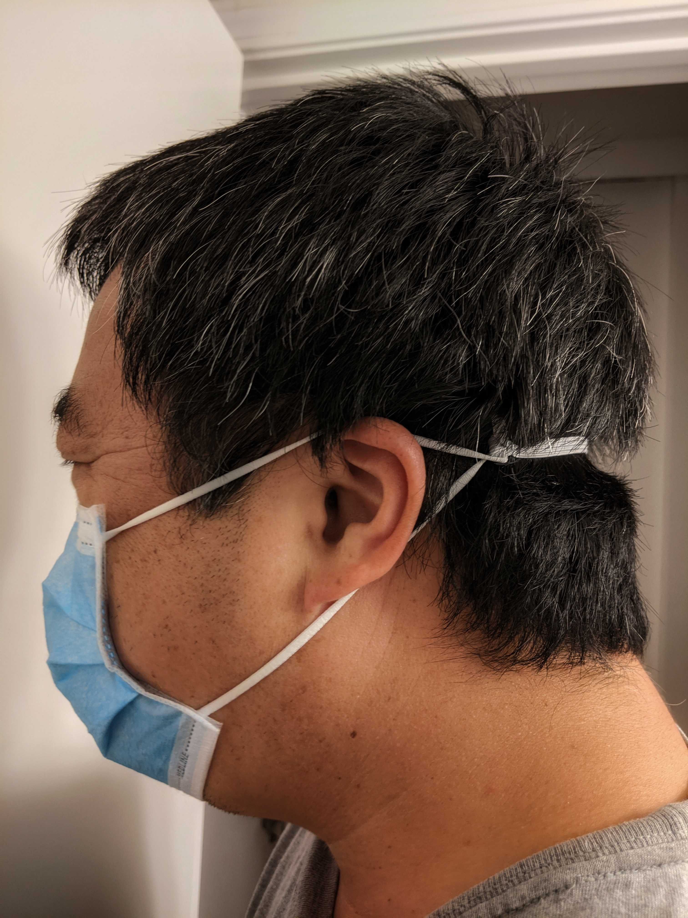
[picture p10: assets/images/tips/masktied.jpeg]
Make your mask time more comfortable
      
    </div>
  </div>  
  <div class="row align-items-center">
    <div class="col-xs-12 col-sm-12 col-md-8 col-lg-8 col-xl-8">
      <h4>Add a mask frame.</h4>
      <p class="text-left">Easily enhance the effectiveness of your face covering by making a mask frame.  Your personalized mask frame will help to seal the air leaks around your face to stop airborne droplets from passing through.  See <b><a href="https://youtu.be/KZgRVWYM7rY" target="_blank">this</a></b> quick how-to video and <b><a href="https://github.com/dickansj/MasterYourPPE/wiki/Improve-Your-Mask-With-a-Frame" target="_blank">print</a></b> a mask frame template with instructions.</p>
      <p class="text-left">You should know that wearing a well-fitting mask for a long time may cause shortness of breath, especially if you are relaxed and breathing shallow.  The solution is to take a few deep breaths while keeping the mask on.  This will help to bring in more fresh air.</p>
    </div>
    <div class="col-xs-12 col-sm-12 col-md-4 col-lg-4 col-xl-4 order-xs-last order-sm-last order-md-first order-lg-first order-xl-first my-4">
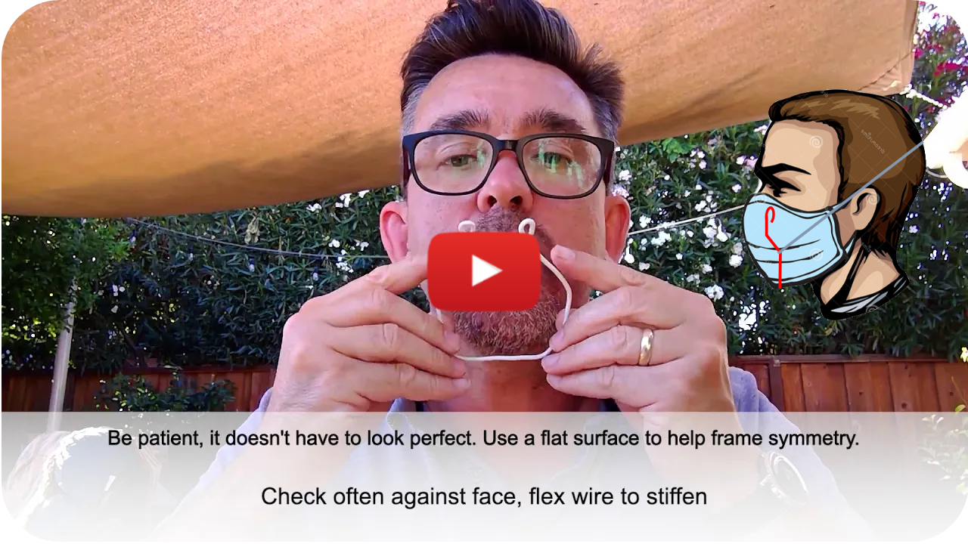
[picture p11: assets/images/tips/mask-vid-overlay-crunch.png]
Add a mask frame
      
    </div>
  </div>
  <div class="row align-items-center">
    <div class="col-xs-12 col-sm-12 col-md-8 col-lg-8 col-xl-8">
      <h4>Completely dried out.</h4>
      <p class="text-left">It’s possible to reuse your surgical mask many times over if it’s had a chance to dry out completely.</p>
      <p class="text-left">Setup an easy mask-rotation program:  First, write numbers on the inside edge on four masks.  Wear the first mask on day 1 then hang it to dry out.  Wear the second mask on day 2 and so on.  When day 5 comes, you can wear the first mask again knowing it has dried out completely.</p>
    </div>
    <div class="col-xs-12 col-sm-12 col-md-4 col-lg-4 col-xl-4 order-xs-last order-sm-last order-md-first order-lg-first order-xl-first my-4">
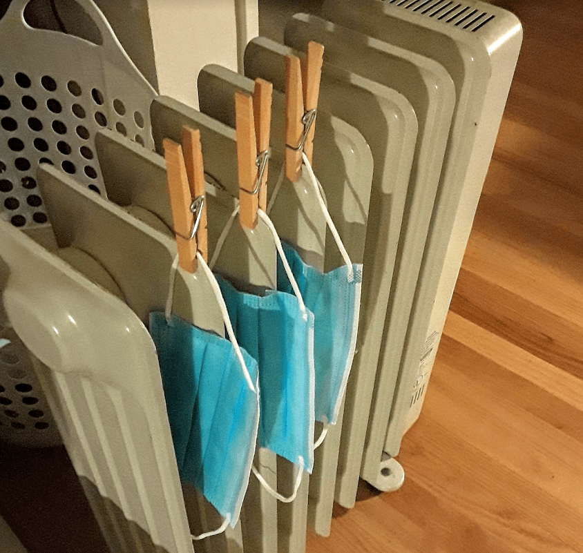
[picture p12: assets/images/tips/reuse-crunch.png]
Reuse your masks safely
      
    </div>
  </div>
  <div class="row align-items-center">
    <div class="col-xs-12 col-sm-12 col-md-8 col-lg-8 col-xl-8">
      <h4>Catch a sneeze.</h4>
      <p class="text-left">Nobody likes to sneeze inside of their mask, gross!  Especially true when you have only one mask with you that needs to stay on for hours.  So, in addition to a spare mask, always carry a clean tissue in your pocket, ready to catch that sneeze.</p>
      <p class="text-left">Remember that one of the main purposes of wearing a mask in public is to stop airborne droplets.  So removing it (even momentarily) to sneeze defeats the objective.  This is where you have to be very diligent in stopping droplets from taking to the air by using a tissue effectively to catch your sneeze.</p>
      <p class="text-left">A tissue is much better at stopping droplets than your bare hands or even the inside of your elbow.  Trash the tissue and wash your hands with soap and water as soon as possible.</p>
    </div>
    <div class="col-xs-12 col-sm-12 col-md-4 col-lg-4 col-xl-4 order-xs-last order-sm-last order-md-first order-lg-first order-xl-first my-4">
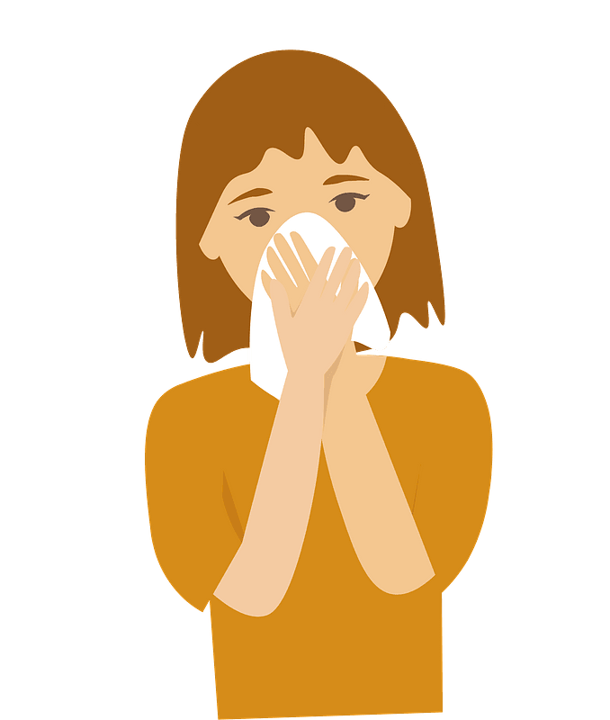
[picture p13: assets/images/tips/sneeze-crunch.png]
Catch your sneeze
      
    </div>
  </div>
  <div class="row align-items-center">
    <div class="col-xs-12 col-sm-12 col-md-8 col-lg-8 col-xl-8">
      <h4>Add a face shield.</h4>
      <p class="text-left">You can make or buy a face shield to wear in conjunction with your face covering for a substantial boost to the effectiveness of just wearing a mask alone.</p>
      <p class="text-left">By wearing a face shield or goggles with your face mask, you can better guard your eyes from larger droplets, which you will more likely encounter when you are within 6 feet of others. CDC <a href="https://www.cdc.gov/coronavirus/2019-ncov/prevent-getting-sick/cloth-face-cover-guidance.html" target="_blank"><b>does not recommend</b></a> using a face shield as a mask <b>substitute</b> because shields typically leave large gaps for droplets around your face. If you have a reusable face shield, you can clean it by following CDC guidelines at the bottom of <a href="https://www.cdc.gov/coronavirus/2019-ncov/hcp/ppe-strategy/eye-protection.html#anchor_1605043382236" target="_blank"><b>this page</b></a>.</p>
    </div>
    <div class="col-xs-12 col-sm-12 col-md-4 col-lg-4 col-xl-4 order-xs-last order-sm-last order-md-first order-lg-first order-xl-first my-4">
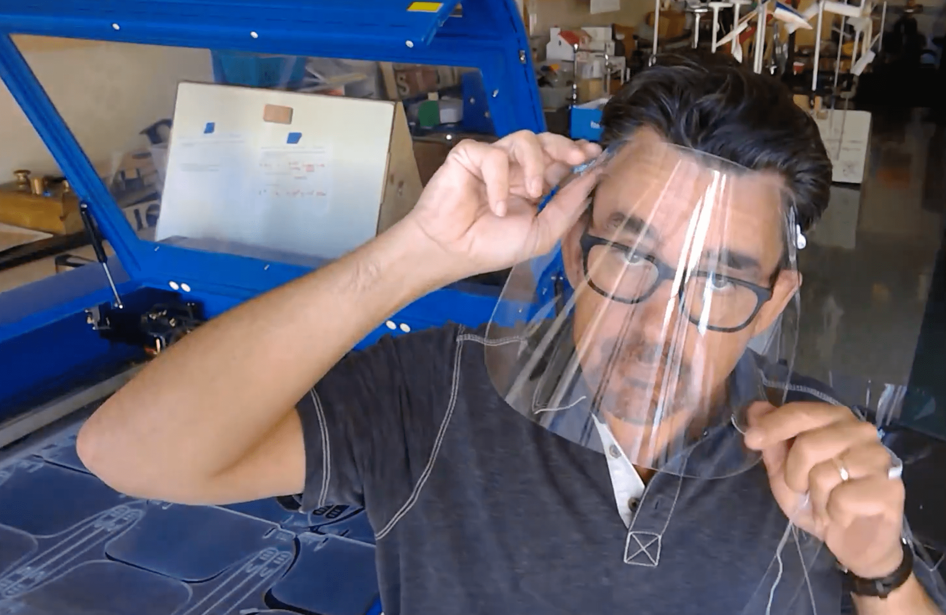
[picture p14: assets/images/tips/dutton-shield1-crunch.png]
Add a face shield
      
    </div>
  </div> 

</div>

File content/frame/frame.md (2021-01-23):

+++

widget = "blank"  # See https://sourcethemes.com/academic/docs/page-builder/
headless = true  # This file represents a page section.
active = true  # Activate this widget? true/false
weight = 10  # Order that this section will appear.

title = ""
subtitle = ""

[design]
  # Choose how many columns the section has. Valid values: 1 or 2.
  columns = "1"

[design.background]
  # Apply a background color, gradient, or image.
  #   Uncomment (by removing `#`) an option to apply it.
  #   Choose a light or dark text color by setting `text_color_light`.
  #   Any HTML color name or Hex value is valid.

  # Background color.
  # color = "navy"
  
  # Background gradient.
  #gradient_start = "#80CED7"
  #gradient_end = "#007EA7"
  
  # Background image.
  # image = "image.jpg"  # Name of image in `static/img/`.
  # image_darken = 0.6  # Darken the image? Range 0-1 where 0 is transparent and 1 is opaque.
  # image_size = "cover"  #  Options are `cover` (default), `contain`, or `actual` size.
  # image_position = "center"  # Options include `left`, `center` (default), or `right`.
  # image_parallax = true  # Use a fun parallax-like fixed background effect? true/false
  
  # Text color (true=light or false=dark).
  text_color_light = false

[design.spacing]
  # Customize the section spacing. Order is top, right, bottom, left.
  padding = ["20px", "0", "20px", "0"]

[advanced]
 # Custom CSS. 
 css_style = ""
 
 # CSS class.
 css_class = ""
+++

<html>
<head>
<meta http-equiv="refresh" content="0;url=https://github.com/dickansj/MasterYourPPE/wiki/Improve-Your-Mask-With-a-Frame" />
<title>Improve Your Mask With a Frame</title>
</head>
</html>

Redirecting to <a href="https://github.com/dickansj/MasterYourPPE/wiki/Improve-Your-Mask-With-a-Frame">the Master Your PPE wiki</a>...

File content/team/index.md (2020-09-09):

---
title: “Who Are We?”  # Add a page title.
summary: "The people and vision behind Master Your PPE"  # Add a page description.
type: "widget_page"  # Page type is a Widget Page
---

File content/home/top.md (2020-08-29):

+++
# A Demo section created with the Blank widget.
# Any elements can be added in the body: https://sourcethemes.com/academic/docs/writing-markdown-latex/
# Add more sections by duplicating this file and customizing to your requirements.

widget = "blank"  # See https://sourcethemes.com/academic/docs/page-builder/
headless = true  # This file represents a page section.
active = false  # Activate this widget? true/false
weight = 10  # Order that this section will appear.

title = ""
subtitle = ""

[design]
  # Choose how many columns the section has. Valid values: 1 or 2.
  columns = "1"

[design.background]
  # Apply a background color, gradient, or image.
  #   Uncomment (by removing `#`) an option to apply it.
  #   Choose a light or dark text color by setting `text_color_light`.
  #   Any HTML color name or Hex value is valid.

  # Background color.
  # color = "navy"
  
  # Background gradient.
  gradient_start = "#80CED7"
  gradient_end = "#007EA7"
  
  # Background image.
  # image = "image.jpg"  # Name of image in `static/img/`.
  # image_darken = 0.6  # Darken the image? Range 0-1 where 0 is transparent and 1 is opaque.
  # image_size = "cover"  #  Options are `cover` (default), `contain`, or `actual` size.
  # image_position = "center"  # Options include `left`, `center` (default), or `right`.
  # image_parallax = true  # Use a fun parallax-like fixed background effect? true/false
  
  # Text color (true=light or false=dark).
  text_color_light = true

[design.spacing]
  # Customize the section spacing. Order is top, right, bottom, left.
  padding = ["20px", "0", "20px", "0"]

[advanced]
 # Custom CSS. 
 css_style = ""
 
 # CSS class.
 css_class = ""
+++

<div class="container-fluid">
  <div class="row">
    <div class="col-xs-12 col-sm-12 col-md-12 col-lg-12 col-xl-12">
      <p class="display-4 text-center mb-0 px-0" style="font-size: calc(145% + 1vw + 1vh);">Master Your PPE</p>
    </div>
    <div class="col-xs-12 col-sm-12 col-md-12 col-lg-12 col-xl-12">
      <p class="lead text-muted text-center mt-0">to keep yourself and those around you healthy.</p>
    </div>
  </div>
</div>
<br>
<div class="container-fluid">
  <div class="row">
    <div class="col-xs-12 col-sm-12 col-md-12 col-lg-6 col-xl-6 mb-4 order-xs-first order-sm-first order-md-first order-lg-last order-xl-last embed-responsive embed-responsive-16by9">
        <iframe class="embed-responsive-item" src="https://www.youtube.com/embed/KZgRVWYM7rY" allow="accelerometer; autoplay; encrypted-media; gyroscope; picture-in-picture" allowfullscreen></iframe>
    </div>
    <div class="col-xs-12 col-sm-12 col-md-12 col-lg-6 col-xl-6 order-xs-last order-sm-last order-md-last order-lg-first order-xl-first my-xs-4 my-sm-4 my-md-4 my-lg-3 my-xl-3">
      <p class = "lead text-center text-lg-left">Learn how in this 1-minute video</p>
      <p class= "cta-btns">
        <a href="https://github.com/dickansj/MasterYourPPE/wiki/Improve-Your-Mask-With-a-Frame" target="_blank" rel="noopener" class="btn cta-btns btn-light btn-lg my-lg-4 my-xl-4 mx-auto d-block float-lg-left" style="color:#32408f; font-size:1.1rem; padding-top: 0.6em; padding-right: 2.1em; padding-bottom: 0.6em; padding-left: 2.1em; line-height: .5; max-width:330px"><i class="fas fa-list-ol pr-1" aria-hidden="true"></i>Step-by-step Guide</a>
      </p>
      <p class= "cta-btns">
        <a class="hero-cta-alt mx-auto d-block float-xs-none float-sm-none float-md-none float-lg-left float-xl-left text-center text-lg-left" href="https://github.com/dickansj/MasterYourPPE/wiki/Improve-Your-Mask-With-a-Frame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" target="_blank" rel="noopener" class="hero-cta-alt pl-4">Share results with #MasterYourPPE <i class="fas fa-angle-right"></i></a>
      </p>
    </div>
  </div>
</div>

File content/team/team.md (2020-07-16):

+++

widget = "blank"  # See https://sourcethemes.com/academic/docs/page-builder/
headless = true  # This file represents a page section.
active = true  # Activate this widget? true/false
weight = 40  # Order that this section will appear.

title = ""
subtitle = ""

[design]
  # Choose how many columns the section has. Valid values: 1 or 2.
  columns = "1"

[design.background]
  # Apply a background color, gradient, or image.
  #   Uncomment (by removing `#`) an option to apply it.
  #   Choose a light or dark text color by setting `text_color_light`.
  #   Any HTML color name or Hex value is valid.

  # Background color.
  # color = "navy"
  
  # Background gradient.
  #gradient_start = "#80CED7"
  #gradient_end = "#007EA7"
  
  # Background image.
  # image = "image.jpg"  # Name of image in `static/img/`.
  # image_darken = 0.6  # Darken the image? Range 0-1 where 0 is transparent and 1 is opaque.
  # image_size = "cover"  #  Options are `cover` (default), `contain`, or `actual` size.
  # image_position = "center"  # Options include `left`, `center` (default), or `right`.
  # image_parallax = true  # Use a fun parallax-like fixed background effect? true/false
  
  # Text color (true=light or false=dark).
  text_color_light = false

[design.spacing]
  # Customize the section spacing. Order is top, right, bottom, left.
  padding = ["20px", "0", "20px", "0"]

[advanced]
 # Custom CSS. 
 css_style = ""
 
 # CSS class.
 css_class = ""
+++

<div class="container my-4">
  <div class="row featurette">
    <div class="col-xs-12 col-sm-12 col-md-12 col-lg-12 col-xl-12 section-heading">
      <h1>Who Are We?</h1>
    </div>
  </div>
  <div class="row align-items-center">
    <div class="col-xs-12 col-sm-4 col-md-4 col-lg-3 col-xl-2 px-4 my-4">
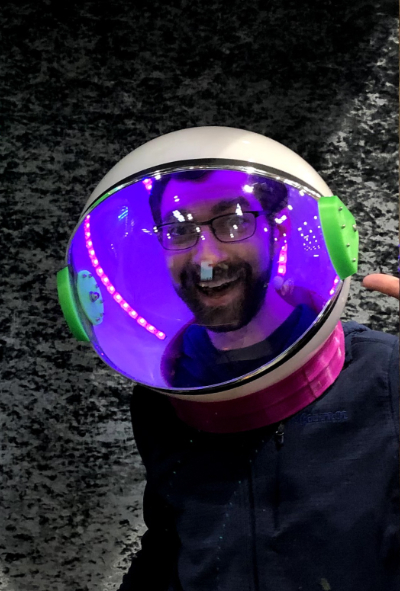
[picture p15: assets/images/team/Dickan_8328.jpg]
Joseph Dickan
      
    </div>
    <div class=" col-xs-12 col-sm-8 col-md-8 col-lg-9 col-xl-10 px-4 my-4">
      <p><b>Joseph Dickan, SJ,</b> is a Jesuit scholastic, educator, and graduate student. He likes neuroscience, computers, and tinkering over a cup of coffee.</p>
    </div>
  </div>
  <div class="row align-items-center">
    <div class="col-xs-12 col-sm-4 col-md-4 col-lg-3 col-xl-2 px-4 my-4">
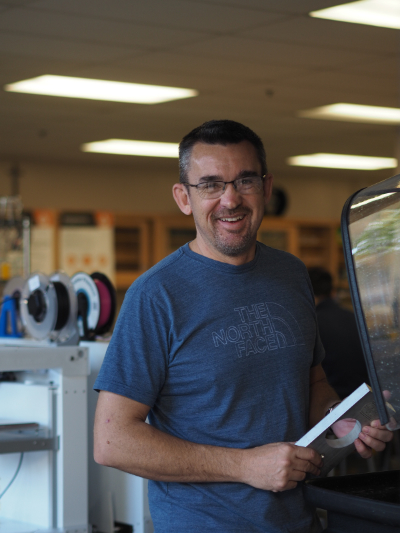
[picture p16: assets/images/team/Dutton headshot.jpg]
David Dutton
      
    </div>
     <div class=" col-xs-12 col-sm-8 col-md-8 col-lg-9 col-xl-10 px-4 my-4">
      <p><b>David Dutton</b> is an educator and Maker Lab Director. He Loves to create, figure stuff out, and mountain bike.</p>
    </div>
  </div>
  <div class="row align-items-center">
    <div class="col-xs-12 col-sm-4 col-md-4 col-lg-3 col-xl-2 px-4 my-4">
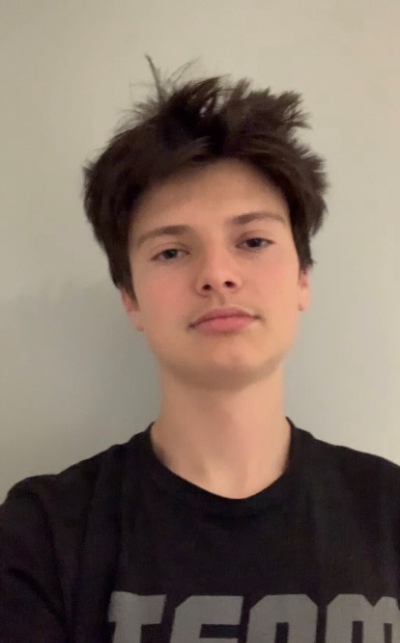
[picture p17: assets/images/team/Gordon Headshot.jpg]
Charles Gordon
      
    </div>
     <div class=" col-xs-12 col-sm-8 col-md-8 col-lg-9 col-xl-10 px-4 my-4">
      <p><b>Aritomo Shinozaki</b> works with startups and does management consulting in product strategy, management, and development. His interests include tooling around with computers, artificial intelligence, the piano, and astronomy.</p>
    </div>
  </div>
  <div class="row align-items-center">
    <div class="col-xs-12 col-sm-4 col-md-4 col-lg-3 col-xl-2 px-4 my-4">
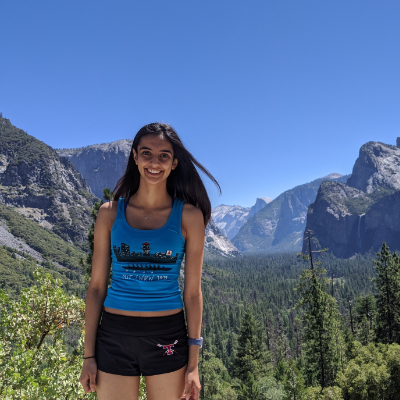
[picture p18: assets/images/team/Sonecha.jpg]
Ria Sonecha
      
    </div>
     <div class=" col-xs-12 col-sm-8 col-md-8 col-lg-9 col-xl-10 px-4 my-4">
      <p><b>Daniel Stefanescu</b> is the instrument manager of an X-ray research facility.  He enjoys science volunteering, tinkering, and learning about the ancient past.</p>
    </div>
  </div>
  <div class="row align-items-center">
    <div class="col-xs-12 col-sm-4 col-md-4 col-lg-3 col-xl-2 px-4 my-4">
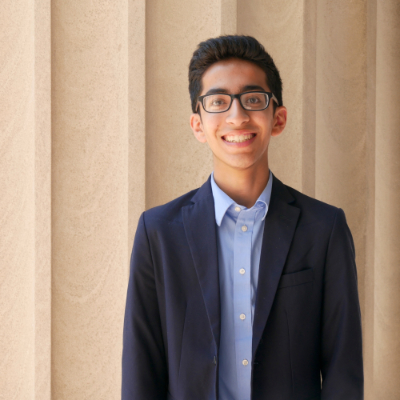
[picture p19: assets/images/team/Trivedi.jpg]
Aadit Trivedi
      
    </div>
     <div class=" col-xs-12 col-sm-8 col-md-8 col-lg-9 col-xl-10 px-4 my-4">
      <p><b>Mihir Trivedi</b> is a student at MIT studying Electrical Engineering and Computer Science. He is a 2017 graduate of Bellarmine College Prep (San Jose) and enjoys hiking and is a pilot in his free time.</p>
    </div>
  </div>
</div>

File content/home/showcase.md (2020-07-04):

+++
# Slider widget.
widget = "slider"  # See https://sourcethemes.com/academic/docs/page-builder/
headless = true  # This file represents a page section.
active = false  # Activate this widget? true/false
weight = 35  # Order that this section will appear.

# Slide interval.
# Use `false` to disable animation or enter a time in ms, e.g. `5000` (5s).
interval = 4000

# Slide height (optional).
# E.g. `500px` for 500 pixels or `calc(100vh - 70px)` for full screen.
height = ""

# Slides.
# Duplicate an `[[item]]` block to add more slides.
[[item]]
  title = "Hello"
  content = "I am center aligned :smile:"
  align = "center"  # Choose `center`, `left`, or `right`.

  # Overlay a color or image (optional).
  #   Deactivate an option by commenting out the line, prefixing it with `#`.
  overlay_color = "#4BB4DE"  # An HTML color value.
  # overlay_img = "headers/bubbles-wide.jpg"  # Image path relative to your `static/img/` folder.
  overlay_filter = 0.5  # Darken the image. Value in range 0-1.

  # Call to action button (optional).
  #   Activate the button by specifying a URL and button label below.
  #   Deactivate by commenting out parameters, prefixing lines with `#`.
  cta_label = "Get Academic"
  cta_url = "https://sourcethemes.com/academic/"
  cta_icon_pack = "fas"
  cta_icon = "graduation-cap"

[[item]]
  title = "Left"
  content = "I am left aligned :smile:"
  align = "left"

  overlay_color = "#4BB4DE"  # An HTML color value.
  overlay_img = ""  # Image path relative to your `static/img/` folder.
  overlay_filter = 0.5  # Darken the image. Value in range 0-1.

[[item]]
  title = "Right"
  content = "I am right aligned :smile:"
  align = "right"

  overlay_color = "#4BB4DE"  # An HTML color value.
  overlay_img = ""  # Image path relative to your `static/img/` folder.
  overlay_filter = 0.5  # Darken the image. Value in range 0-1.
+++

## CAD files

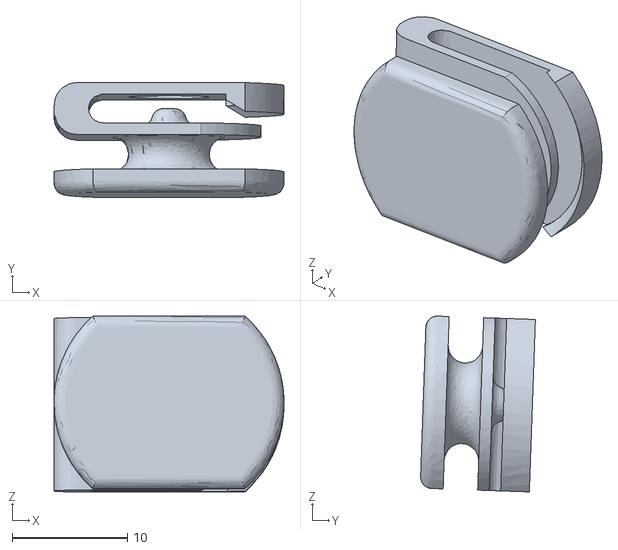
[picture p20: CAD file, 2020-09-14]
designs/facemask/maskclip/MaskClipv3.stl
20.0 x 9.98 x 15.3

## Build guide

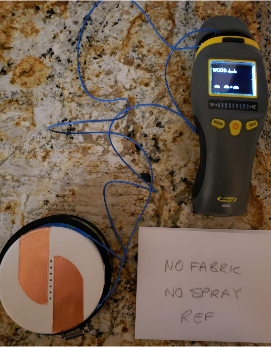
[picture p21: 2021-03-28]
assets/images/testing/moisture-setup.png

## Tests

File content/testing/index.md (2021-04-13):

---
title: "PPE Performance"  # Add a page title.
summary: "Our (non-scientific) PPE tests to find the masks that best filter small particles and resist moisture penetration."  # Add a page description.
type: "widget_page"  # Page type is a Widget Page
---

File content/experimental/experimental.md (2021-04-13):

+++

## This is a template for a blank page section.
## Copy into a new md file. Remember to change active to "true" and use weight to set order on page.
## You can use the other options below, just uncomment as needed.
## Place any html after the bottom 3 plus signs. You can use the div container with Bootstrap classes.
## See https://getbootstrap.com/docs/4.5/layout/grid/ and the docs there (or other content/home md files on this site) for examples.

widget = "blank"  # See https://sourcethemes.com/academic/docs/page-builder/
headless = true  # This file represents a page section.
active = true  # Activate this widget? true/false
weight = 40  # Order that this section will appear.

title = ""
subtitle = ""

[design]
  # Choose how many columns the section has. Valid values: 1 or 2.
  columns = "1"

[design.background]
  # Apply a background color, gradient, or image.
  #   Uncomment (by removing `#`) an option to apply it.
  #   Choose a light or dark text color by setting `text_color_light`.
  #   Any HTML color name or Hex value is valid.

  # Background color.
  # color = "navy"
  
  # Background gradient.
  #gradient_start = "#80CED7"
  #gradient_end = "#007EA7"
  
  # Background image.
  # image = "image.jpg"  # Name of image in `static/img/`.
  # image_darken = 0.6  # Darken the image? Range 0-1 where 0 is transparent and 1 is opaque.
  # image_size = "cover"  #  Options are `cover` (default), `contain`, or `actual` size.
  # image_position = "center"  # Options include `left`, `center` (default), or `right`.
  # image_parallax = true  # Use a fun parallax-like fixed background effect? true/false
  
  # Text color (true=light or false=dark).
  text_color_light = false

[design.spacing]
  # Customize the section spacing. Order is top, right, bottom, left.
  padding = ["20px", "0", "20px", "0"]

[advanced]
 # Custom CSS. 
 css_style = ""
 
 # CSS class.
 css_class = ""
+++

<script src="https://raw.githubusercontent.com/dickansj/MasterYourPPE/master/assets/js/newsCollapse.js"></script>

<div class="container" style="min-width: 0; min-height: 0">

  <div class="row justify-content-center">
    <div class="col-xs-12 col-sm-12 col-md-6 col-lg-6 col-xl-6 mb-4 text-center">
      <button class="btn btn-primary" type="button" style="min-width: 0" data-toggle="collapse" data-target="#moisture" role="button" aria-expanded="false" aria-controls="moisture" onclick="location.href = '#moisture';">
        <i class="fas fa-tint"></i>&nbsp;&nbsp;<b>Moisture Penetration</b>
      </button>
    </div>
    <div class="col-xs-12 col-sm-12 col-md-6 col-lg-6 col-xl-6 mb-4 text-center">
      <button class="btn btn-primary" type="button" style="min-width: 0" data-toggle="collapse" data-target="#particle" role="button" aria-expanded="false" aria-controls="particle" onclick="location.href = '#moisture';">
        <i class="fas fa-shield-alt"></i>&nbsp;&nbsp;<b>Particle Filtration</b>
      </button>
    </div>
  </div>
   
  <p></p>
  <div class="collapse show" id="moisture">
    <div class="row my-4">
      <div class="col-xs-12 col-sm-12 col-md-12 col-lg-12 col-xl-12">
        <h3>How well do different masks block water droplets?</h3>
        <p class="text-left">Since exposure to contaminated respiratory droplets is a common means of viral infection (and the <b><a href="https://www.cdc.gov/coronavirus/2019-ncov/science/science-briefs/scientific-brief-sars-cov-2.html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" target="_blank">primary mode of SARS-CoV-2 infection</a></b>), we tested how different masks block water droplets, simulating droplets from a cough or sneeze. When water droplets land on a solid surface, they can either ball up without penetrating the material (which is <em>hydrophobic</em>, or "water-hating"), or they can wet the surface and soak through the <em>hydrophilic</em> ("water-loving") material. So we wanted to find out what kind of mask would best resist moisture penetration.</p>
      </div>
    </div>
    <div class="row align-items-center mb-4">
      <div class="col-xs-12 col-sm-12 col-md-12 col-lg-11 col-xl-11">
        <h5>Results</h5>
        <p class="text-left"><i class="fas fa-times" style="color: #ff7600"></i>&nbsp;&nbsp;<em>Single-ply materials</em>, such as poly blends and cotton, showed immediate penetration to the inside when the top surface was sprayed with water.</p>
        <p class="text-left"><i class="fas fa-times" style="color: #ff7600"></i>&nbsp;&nbsp;Cotton gave moisture readings even before spraying, due to its hydrophilic nature.</p>
        <p class="text-left"><i class="fas fa-times" style="color: #ff7600"></i>&nbsp;&nbsp;Masks made from 100% polyester were dry at first but did allow water penetration.</p>
        <p class="text-left"><i class="fas fa-check" style="color: #68cd00"></i></i>&nbsp;&nbsp;Various <em>3-ply masks</em> that performed well in our particle filtration tests also resisted water significantly better than single-ply masks. See our data below for detail.</p>
      </div>
    </div>
    <div class="row align-items-center mx-4 mb-4">
      <div class="col-xs-12 col-sm-12 col-md-12 col-lg-12 col-xl-12 mx-auto d-block float-xs-none">
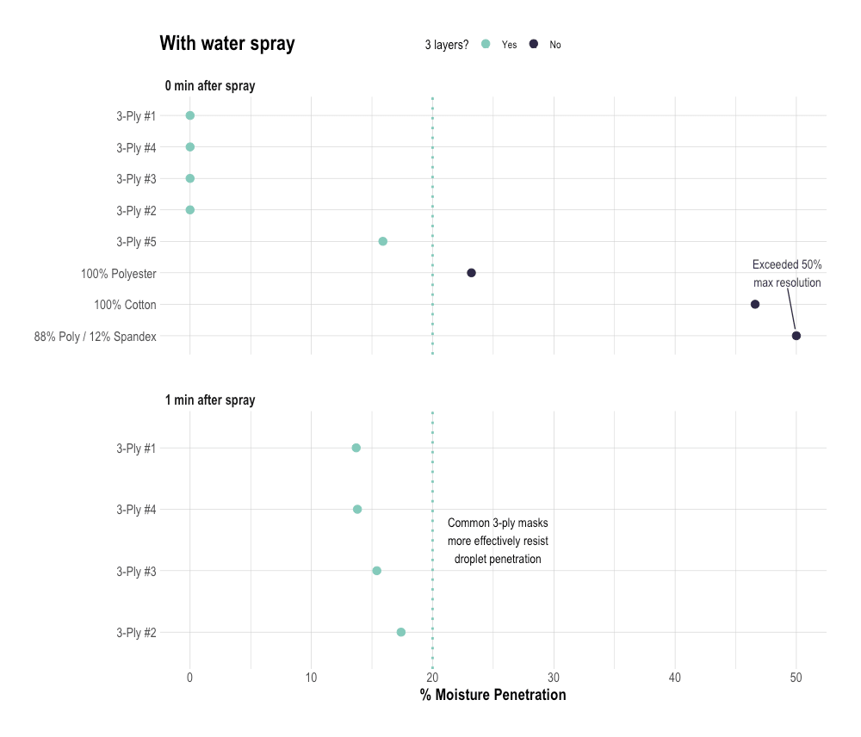
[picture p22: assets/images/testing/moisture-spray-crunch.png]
Comparison of Moisture Penetration in Masks: With Water Spray
         
      </div>
      <div class="col-xs-12 col-sm-12 col-md-12 col-lg-12 col-xl-12 mx-auto d-block float-xs-none">
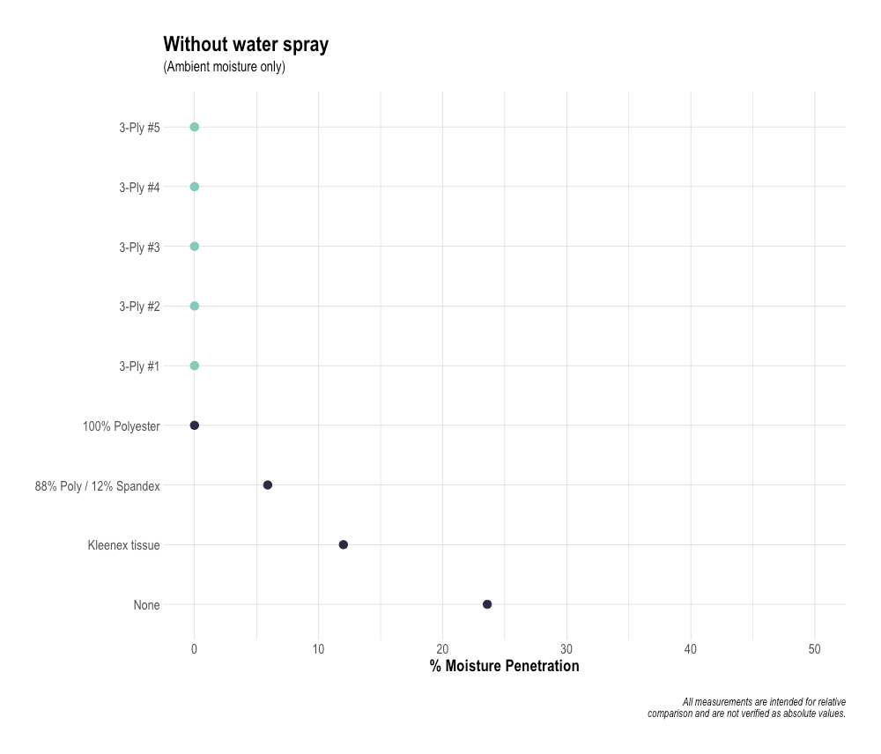
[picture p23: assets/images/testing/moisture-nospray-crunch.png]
Comparison of Moisture Penetration in Masks: Without Water Spray
         
      </div>
    </div>
    <div class="row align-items-center mb-4 justify-content-between">
      <div class="col-xs-12 col-sm-12 col-md-12 col-lg-8 col-xl-6">      
        <h5>Setup</h5>
        <p class="text-left">We measured the water penetration of various mask materials with a moisture meter typically used to measure water content in wood or plaster board. When the meter's two probes are inserted into a material, any water present will conduct electricity between the probes, and the meter measures this conductivity.</p>
      </div>
      <div class="col-xs-12 col-sm-12 col-md-12 col-lg-4 col-xl-6 flex-grow-1">
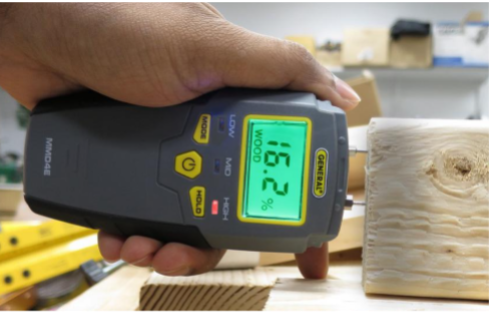
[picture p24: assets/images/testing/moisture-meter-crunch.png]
moisture meter
        
      </div>
    </div>
    <div class="row align-items-center mb-4 justify-content-between">
      <div class="col-xs-12 col-sm-12 col-md-12 col-lg-12 col-xl-4">
        <p class="text-left">We modified the probes into large copper pads that would sit behind the face mask, detecting if water had penetrated through the material to the copper pad test side.</p>
      </div>
      <div class="col-xs-12 col-sm-12 col-md-6 col-lg-6 col-xl-5 my-4 flex-xs-grow-1 flex-sm-grow-1">
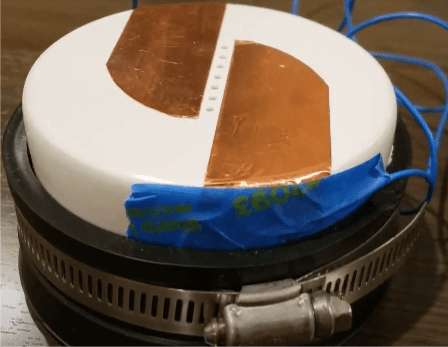
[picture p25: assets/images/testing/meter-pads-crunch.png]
moisture meter pads
        
      </div>
      <div class="col-xs-12 col-sm-12 col-md-4 col-lg-4 col-xl-3 my-4 flex-xs-grow-1 flex-sm-grow-1">
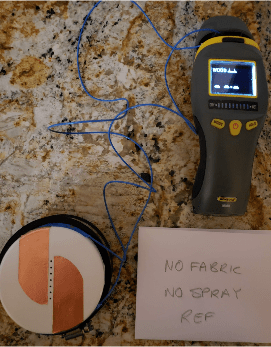
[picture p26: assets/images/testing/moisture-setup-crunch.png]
moisture meter setup
        
      </div>
    </div>
    <div class="row mb-4">
      <div class="col-xs-12 col-sm-12 col-md-12 col-lg-12 col-xl-12">
        <p class="text-left">The copper pads were mounted on a PVC surface with holes drilled along the gap. These holes connected to a flexible plenum, provided by a rubber diaphragm. This setup simulated human breath and provided a slow flow of air through the mask during tests.</p>
        <p class="text-left">Moisture readings were taken under variable conditions, including with and without the application of skin contact and water spray.</p>
      </div>
    </div>
    <div class="row align-items-center">
      <div class="col-xs-12 col-sm-12 col-md-11 col-lg-4 col-xl-4 mx-auto d-block mb-4">
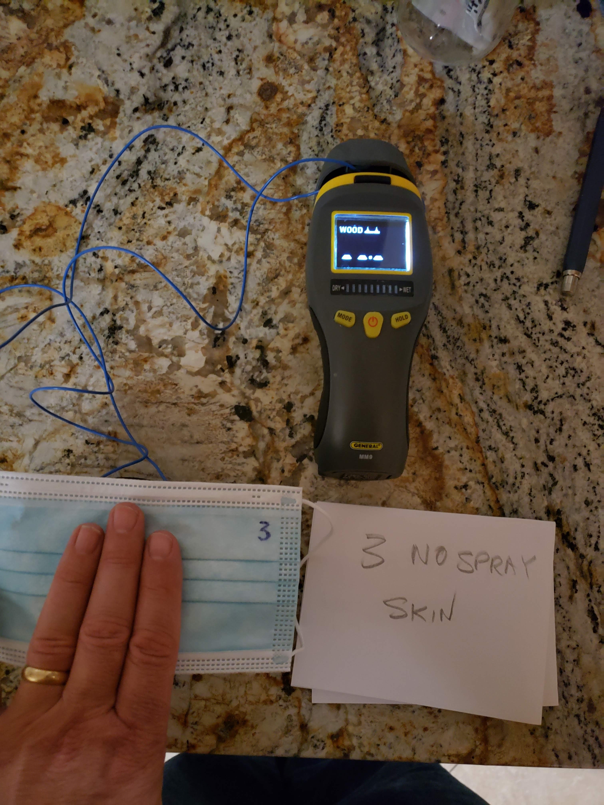
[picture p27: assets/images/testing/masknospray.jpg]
Mask setup no spray
                
      </div>
      <div class="col-xs-12 col-sm-12 col-md-11 col-lg-4 col-xl-4 mx-auto d-block mb-4">
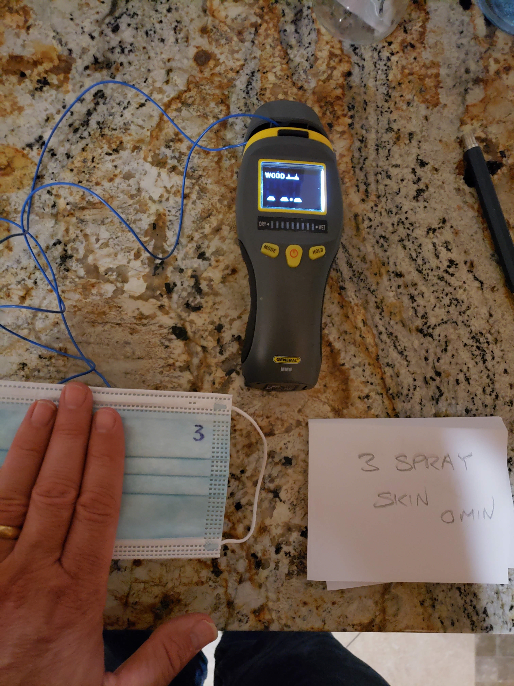
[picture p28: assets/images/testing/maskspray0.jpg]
Mask setup spray 0 min
        
      </div>
      <div class="col-xs-12 col-sm-12 col-md-11 col-lg-4 col-xl-4 mx-auto d-block mb-4">
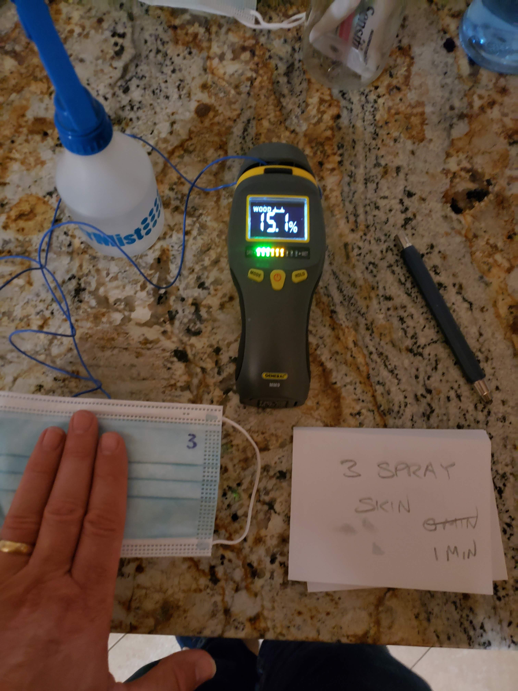
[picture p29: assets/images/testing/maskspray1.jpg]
Mask setup spray 1 min
        
      </div>
    </div>
  </div>
  
  <div class="collapse" id="particle">
    <div class="row">
      <div class="col-xs-12 col-sm-12 col-md-12 col-lg-12 col-xl-12">
        <h3>How well do common masks filter particles?</h3>
        <p class="text-left">In addition to moisture penetration, we measured in our sample masks a second indicator of their efficacy: the percentage of small particles blocked by each mask material. So which mask types best filter particles in the size range of airborne droplets?</p>
        <br>
        <h5>Results</h5>
        <p class="text-left"><i class="fas fa-times" style="color: #ff7600"></i>&nbsp;&nbsp;<em>Household fabrics</em> and masks made from <em>polyester or cotton</em> offered relatively weak filtration, though they likely still provide some benefit.</p>
        <p class="text-left"><i class="fas fa-check" style="color: #68cd00"></i></i>&nbsp;&nbsp;Masks with <em>3 layers</em> (including common surgical masks) showed filtration nearly identical to that of medical-grade N95 masks, blocking more than 95% of particles in many cases.</p>
        <br>
        <p> This plot compares the actual filtering efficiency of masks and materials for particle sizes of 1um and 0.3um.  Note that 0.3um is the size used in industry for particle filtering efficiency rating. </p>
      </div>
    </div>
    <div class="row align-items-center mt-4">
      <div class="col-xs-12 col-sm-12 col-md-12 col-lg-10 col-xl-9 mx-auto d-block float-xs-none">
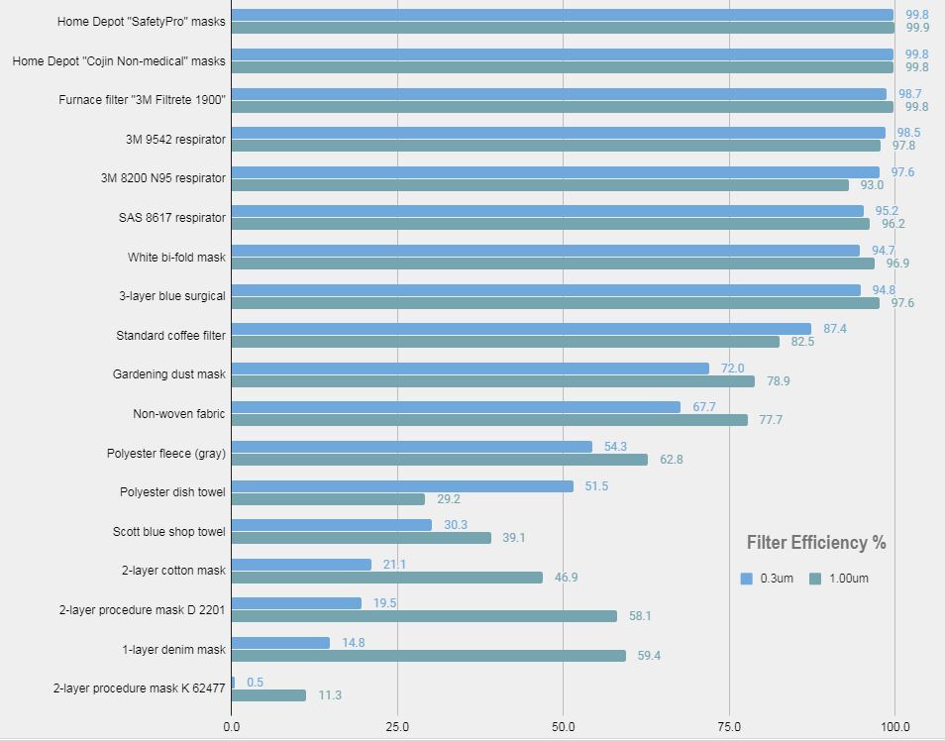
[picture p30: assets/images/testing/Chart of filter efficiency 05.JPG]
Comparison of Filtration Efficiencies
         
      </div>
    </div>
    <div class="row justify-content-center">
      <div class="col-xs-12 col-sm-12 col-md-12 col-lg-10 col-xl-9 mb-4>
        <p class="text-justify"><em>The 0.3- and 1.00-micron filtration efficiencies of different filter materials, masks, and respirators.</em></p>
      </div>
    </div>
    <div class="row align-items-left">
      <div class="col-xs-12 col-sm-12 col-md-12 col-lg-12 col-xl-12">
        <h5>Setup</h5>
      </div>
    </div>
    <div class="row align-items-center justify-content-around">
      <div class="col-xs-12 col-sm-12 col-md-8 col-lg-8 col-xl-8">
        <p class="text-left">We used a Fluke 985 Particle Counter to measure the filtration efficiency of commercially available masks and respirators and that of other commonly available materials (more than 70 samples in total).  The testing apparatus consisted of a 4-inch PVC pipe cap with a 1/2-inch access hole drilled on the side where the particle counter's conical test port was inserted.  Above the access hole, we mounted an adjustable hose clamp to provide a tight seal between the cap and the filter material being tested.  Each material was tested for two minutes and the data was normalized against unfiltered measurements of the room air.  Subsequent testing of the same filter material yielded slightly different counts; however the variation was usually below 0.5% of the initial values.</p>
      </div>
      <div class="col-xs-12 col-sm-12 col-md-4 col-lg-4 col-xl-4 order-xs-last order-sm-last order-md-first order-lg-first order-xl-first my-4" style="max-width:288px;">
        testing1
      </div>
    </div>
    <div class="row align-items-center justify-content-around">
      <div class="col-xs-12 col-sm-12 col-md-4 col-lg-4 col-xl-4 my-4" style="max-width:288px;">
        testing2
      </div>
      <div class="col-xs-12 col-sm-12 col-md-8 col-lg-8 col-xl-8">
        <p class="text-left">The reader should note that these test results are <b>not</b> scientifically valid.  The results may provide a fair indication of filter efficiency and could be used to compare the performance of filter material types. However, the results do not imply that the data should be relied upon to make actionable decisions on filter, mask, or respirator selection.</p>    
      </div>
    </div>
  </div>
    
</div>

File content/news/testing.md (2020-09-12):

+++

widget = "blank"  # See https://sourcethemes.com/academic/docs/page-builder/
headless = true  # This file represents a page section.
active = true  # Activate this widget? true/false
weight = 40  # Order that this section will appear.

title = ""
subtitle = ""

[design]
  # Choose how many columns the section has. Valid values: 1 or 2.
  columns = "1"

[design.background]
  # Apply a background color, gradient, or image.
  #   Uncomment (by removing `#`) an option to apply it.
  #   Choose a light or dark text color by setting `text_color_light`.
  #   Any HTML color name or Hex value is valid.

  # Background color.
  # color = "navy"
  
  # Background gradient.
  #gradient_start = "#80CED7"
  #gradient_end = "#007EA7"
  
  # Background image.
  # image = "image.jpg"  # Name of image in `static/img/`.
  # image_darken = 0.6  # Darken the image? Range 0-1 where 0 is transparent and 1 is opaque.
  # image_size = "cover"  #  Options are `cover` (default), `contain`, or `actual` size.
  # image_position = "center"  # Options include `left`, `center` (default), or `right`.
  # image_parallax = true  # Use a fun parallax-like fixed background effect? true/false
  
  # Text color (true=light or false=dark).
  text_color_light = false

[design.spacing]
  # Customize the section spacing. Order is top, right, bottom, left.
  padding = ["20px", "0", "20px", "0"]

[advanced]
 # Custom CSS. 
 css_style = ""
 
 # CSS class.
 css_class = ""
+++

<div class="container-fluid">
  <div class="row">
    <div class="col-xs-12 col-sm-12 col-md-12 col-lg-12 col-xl-12">
      <h3>Filtering efficiency of common masks and materials.</h3>
      <p> This plot compares the actual filtering efficiency of masks and materials for droplet sizes of 1um and .3um.  Note that .3um is the size used in industry for particle filtering efficiency rating. </p>
    </div>
  </div>
  <div class="row align-items-center mt-4">
    <div class="col-xs-12 col-sm-12 col-md-12 col-lg-10 col-xl-9 mx-auto d-block float-xs-none">
       Comparison of Filtration Efficiencies
    </div>
  </div>
  <div class="row justify-content-center">
    <div class="col-xs-12 col-sm-12 col-md-12 col-lg-10 col-xl-9 mb-4>
      <p class="text-justify"><em>The 0.3- and 1.00-micron filtration efficiencies of different filter materials, masks, and respirators.</em></p>
    </div>
  </div>
  <div class="row align-items-left">
    <div class="col-xs-12 col-sm-12 col-md-12 col-lg-12 col-xl-12">
      <h3>How we tested the masks and materials</h3>
    </div>
  </div>
  <div class="row align-items-center">
    <div class="col-xs-12 col-sm-12 col-md-4 col-lg-3 col-xl-3 mx-4">
      testing1
    </div>
      <div class="col-xs-12 col-sm-12 col-md-4 col-lg-3 col-xl-3 mx-4">
        testing2
      </div>
  </div>
  <br>

<div class="row">
      <p>We used a Fluke 985 Particle Counter to measure the filtration efficiency of several commercially available masks and respirators and that of other commonly available materials.  The testing apparatus consisted of a 4-inch PVC pipe cap with a 1/2-inch access hole drilled on the side where the particle counter's conical test port was inserted.  Above the access hole, we mounted an adjustable hose clamp to provide a tight seal between the cap and the filter material being tested.  Each material was tested for two minutes and the data was normalized against unfiltered measurements of the room air.  Subsequent testing of the same filter material yielded slightly different counts; however the variation was usually below 0.5% of the initial values.</p>
    
  <p>The reader should note that these test results are <b>not</b> scientifically valid.  The results may provide a fair indication of filter efficiency and could be used to compare the performance of filter material types. However, the results do not imply that the data should be relied upon to make actionable decisions on filter, mask, or respirator selection.</p>    
</div>

</div>

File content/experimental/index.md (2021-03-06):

---
title: "Master Your PPE"  # Add a page title.
summary: "Videos to help you get the most out of your personal protective equipment."  # Add a page description.
type: "widget_page"  # Page type is a Widget Page
---

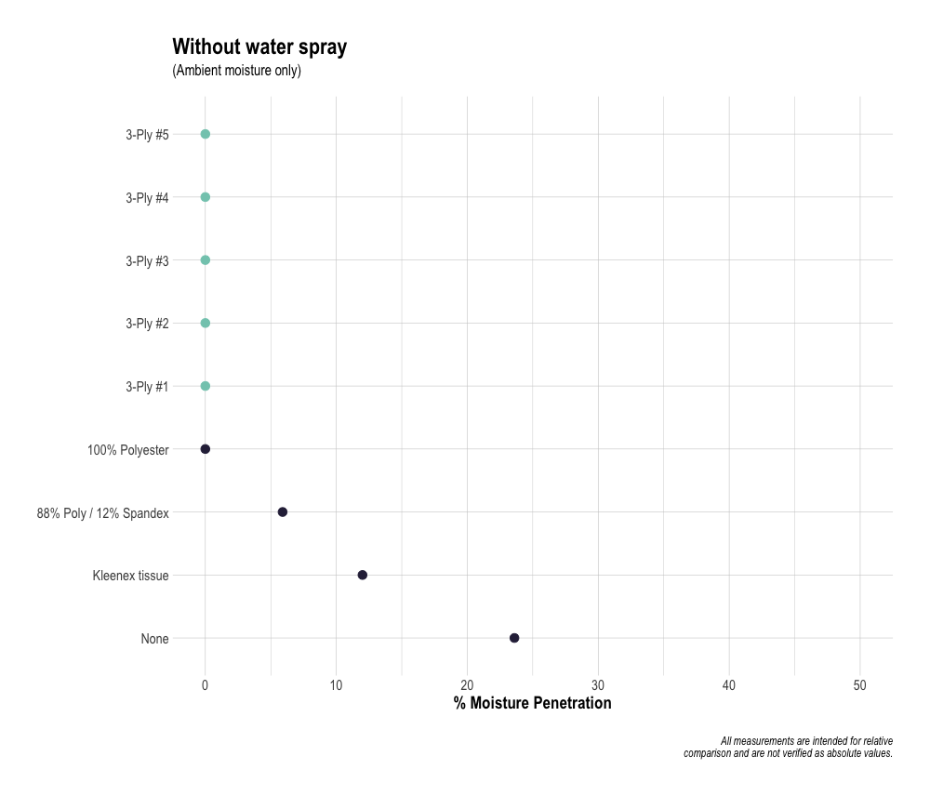
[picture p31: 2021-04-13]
assets/images/testing/moisture-nospray.png

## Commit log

2020-07-04 Added frame template
2020-07-09 New frame template
2020-07-16 Add side view frame
2020-08-07 Add filter efficiency 05
2020-08-28 Update menu Daniel’s headings
2020-09-12 removed the play button from image
2020-09-13 Add mask frame model
2020-09-14 Add MaskClipv3
    [MaskClipv3.stl]
2020-09-14 Add maskclip directory
    [MaskClipv3.stl]
2020-10-08 Add deep breaths and mask frame image
2020-10-08 upodate mask frame vid
2020-10-08 Add transparency to frame side view
2020-10-09 Add small mask frame image
2020-10-17 Restore news button sizing
2020-10-23 Add news button box shadow
2020-10-23 News top formatting/buttons
2020-10-23 Add news button onclick anchor
2020-10-24 Test button width 0
2020-10-24 Test button min width
2021-01-23 add frame redirect
2021-01-30 Add mask frame link
2021-01-30 Justify frame caption
2021-01-30 Adjust frame caption alignment
2021-03-13 Switch to optimized images (site)
2021-03-13 Revert double mask alignment
    Need to play with alignment…
2021-04-03 Test experimental collapse buttons
